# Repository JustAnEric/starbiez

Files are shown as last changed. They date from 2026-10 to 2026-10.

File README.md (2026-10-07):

# StarbieZ (star-beez)

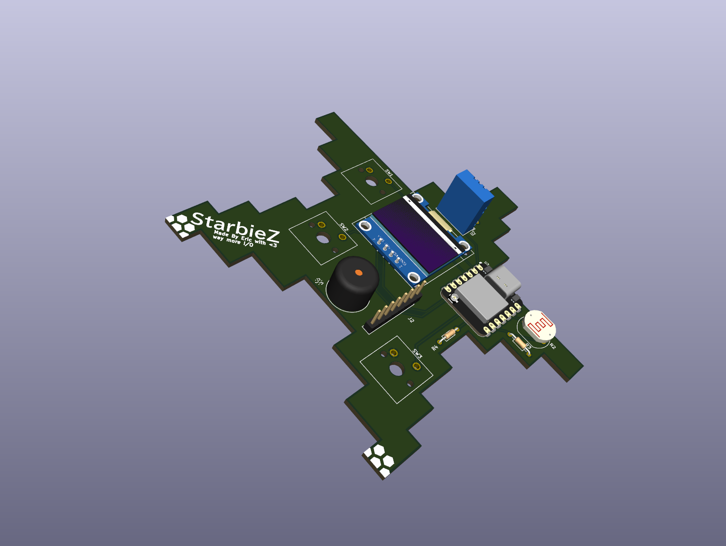
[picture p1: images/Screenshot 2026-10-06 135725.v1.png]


Starbiez is a redo of the [Starbie](https://github.com/SharKingStudios/Starbie), and boy it packs *serious* power!

You're now getting your own extendible Tamagotchi that can run MANY things, basically sort of like a *Flipper Zero Nano* but without the pentesting tools! (don't go hacking things around town with this... :C)

## What it does

the ESP32-S3 Plus is where I'd start the shift from MCU to CPU, and it's the main driver for this project. With 16 MB of flash and 8 MB of RAM, it's way more than all the classic Tamagotchis that had **1 KB of RAM and ROM**! this Starbie is equipped with greater environmental awareness, audio and just *one more* button that adds so many more possibilities for what can be done with this project.

the environment can be currently measured by these sensors:

* a light dependent resistor on the right front face of the board
* a DHT11 humidity sensor on the top front face of the board
* AND a 6 pin IMU called the MPU6050 at the bottom right of the board!

the outputs on this device are *pretty simple*:
* 128x64 SSD1306 OLED screen
* buzzer/piezo

you provide input to this project by literally just clicking the cherry MX keyboard switches... and the circuitpython software being packaged for this project is considerably extendable being based off of the C++/.INO software. (yes, I'm rewriting/have rewritten it to make it easier for extensions, welcome beginners!)

## The process of building
### Day 1!

I spent the whole day, and I quite probably went past 4 hours (the actual making time of my board) to include the things that would make it my own...

You can see the **timestamps in the screenshot names**, for journal purposes I didn't replace them with a generic name throughout my processes!

How to interpret them:

* Example: `Screenshot 2026-10-06 064450.png`
* `2026-`: The year
* `10-`: The month
* `06`: The day
* `064450`:
    * `06`: The hour of the day (in AEST/AEDT, since I'm working on it in Australia/Sydney!)
    * `44`: The minute of the hour `06`
    * `50`: The seconds the screenshot was taken at

Hope this helps!

1. I created the project and crafted the schematic from the [tutorial](https://github.com/SharKingStudios/Starbie)

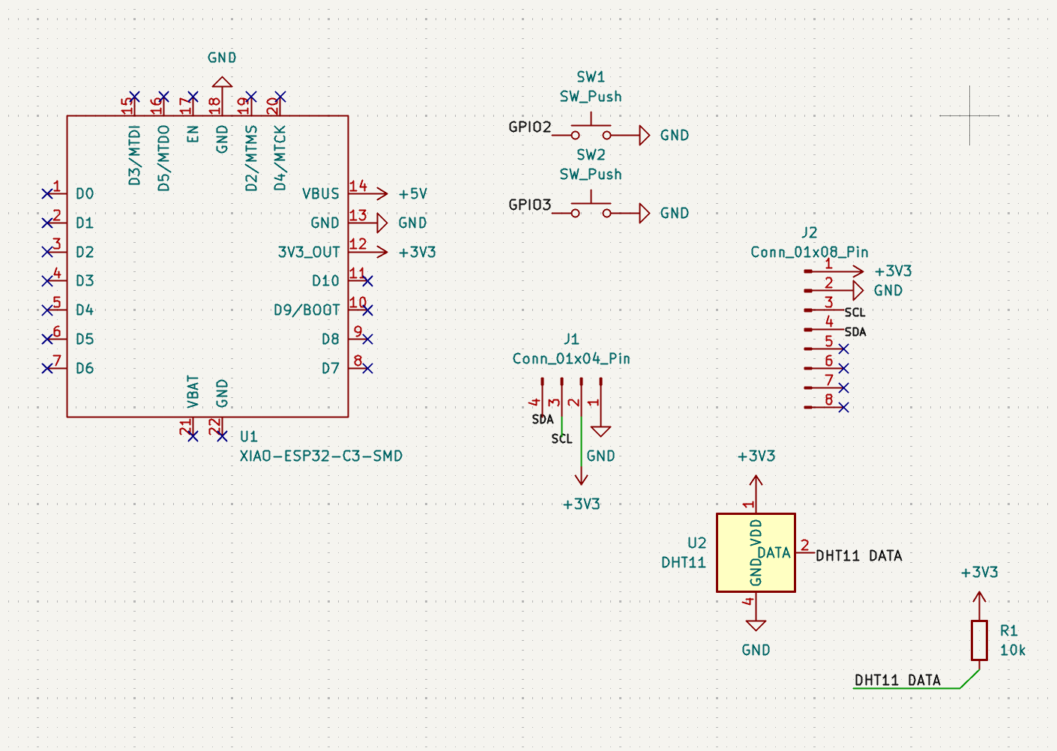
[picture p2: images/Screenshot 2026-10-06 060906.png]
    

2. I laid out my PCB, creating the star `Edge.Cuts` from a reference image I found on Google first

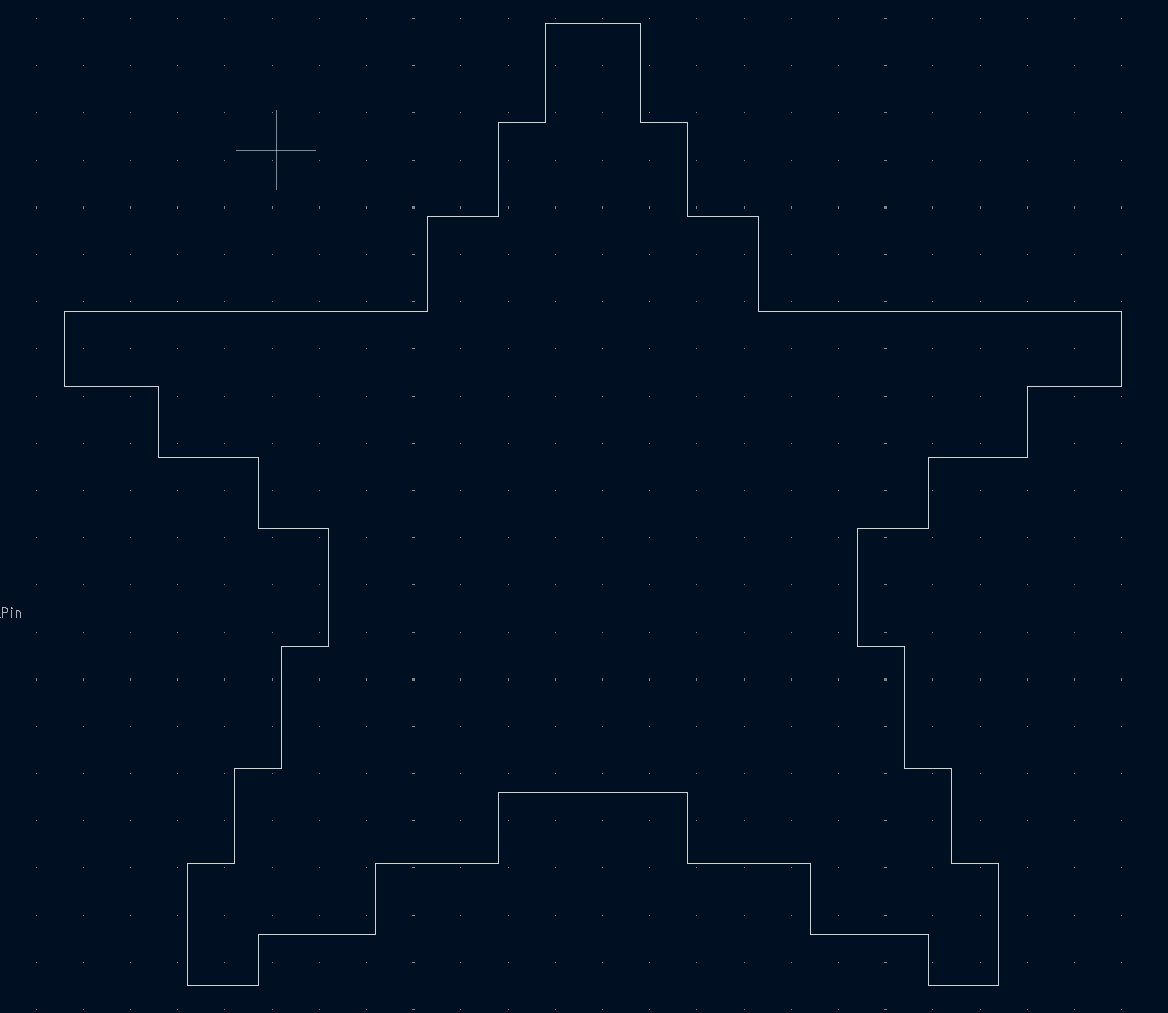
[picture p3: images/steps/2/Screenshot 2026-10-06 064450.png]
    
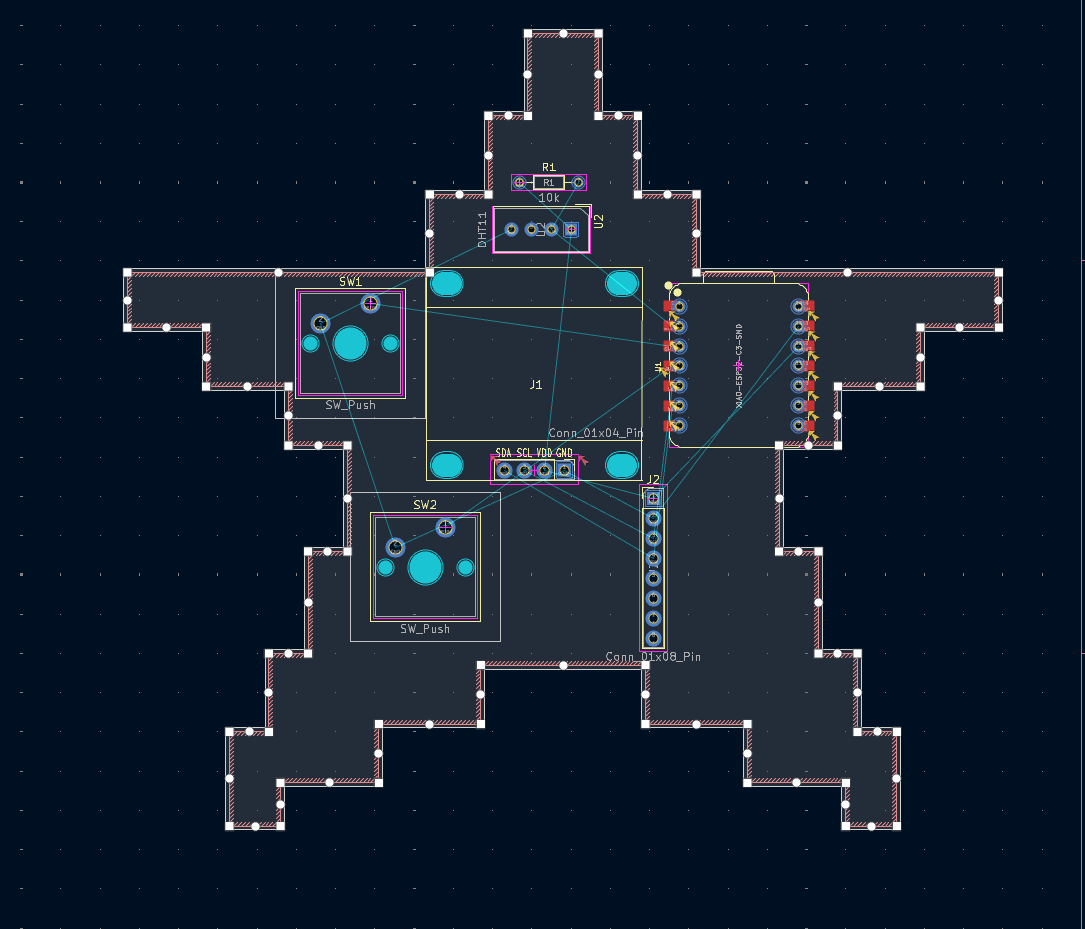
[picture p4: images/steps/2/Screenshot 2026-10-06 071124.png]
    

    and then the satisfying ground layer by the B button...
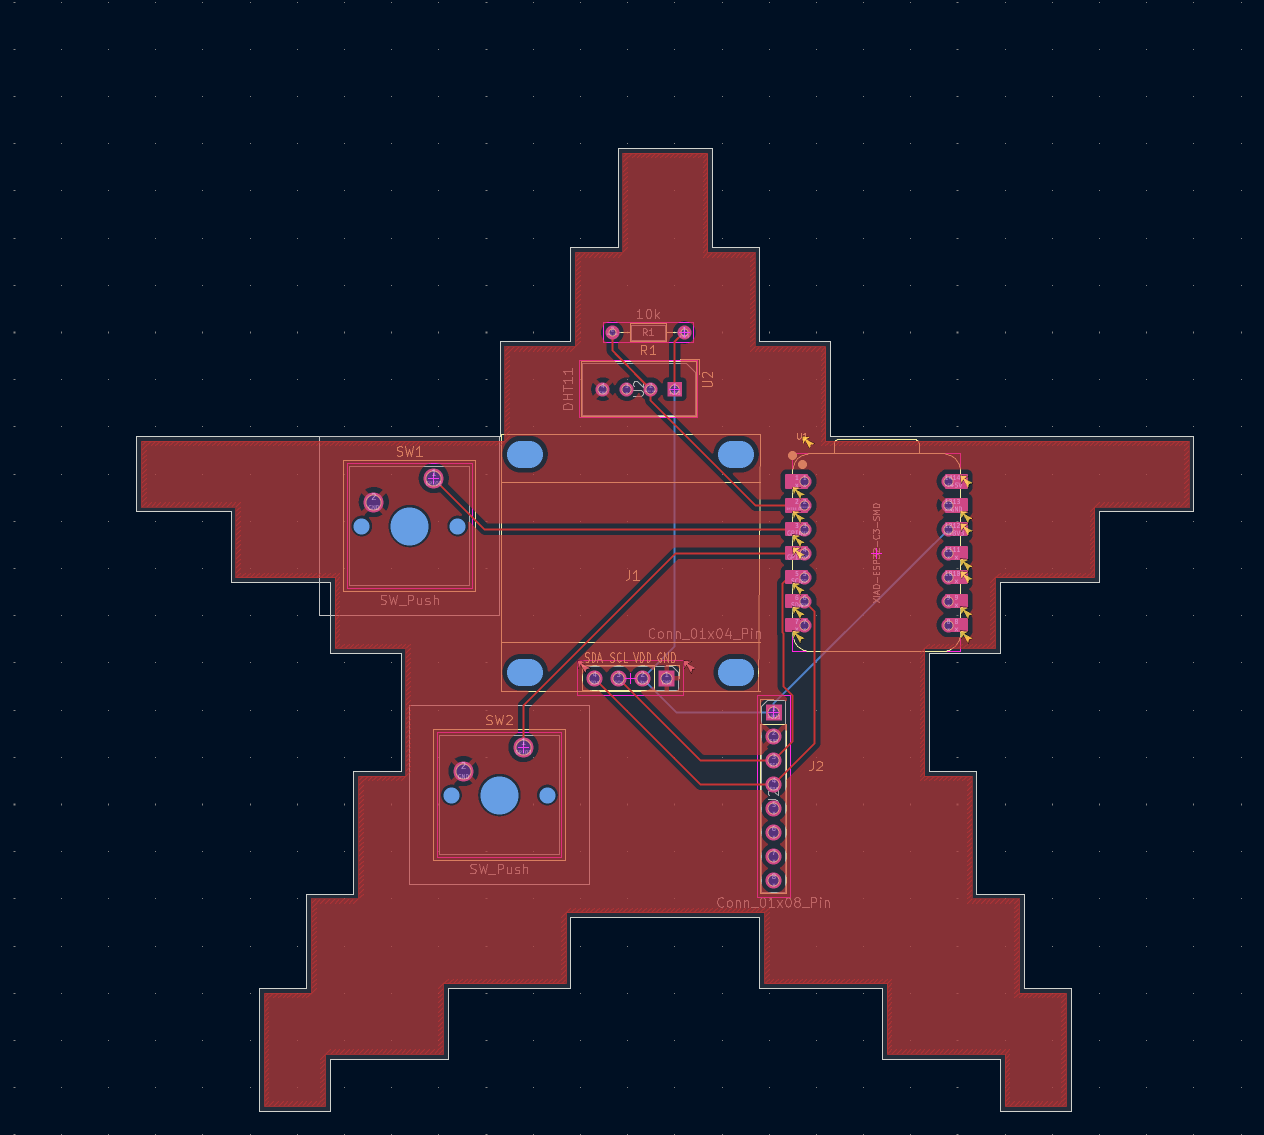
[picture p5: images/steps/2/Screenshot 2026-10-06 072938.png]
    

    Those steps took about 4 hours and 5 minutes, timed by Google stopwatch (thanks search engine monopoly... never mind)

3. One of my first modifications was with changing the MCU from an ESP32-C3 to an ESP32-S3. My first strongest candidate.

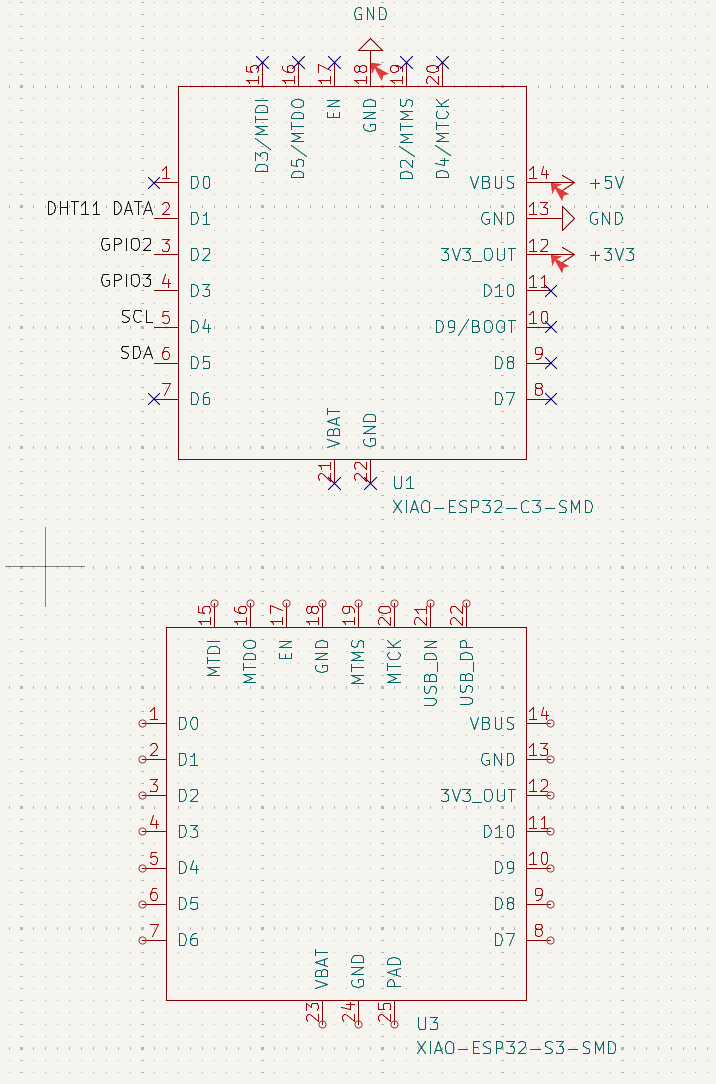
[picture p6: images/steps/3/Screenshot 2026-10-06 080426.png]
    

    This swap didn't take very long... They're very structurally similar. I made sure to check Seeed's official guides though, just in case I got the pinouts wrong.

4. I included a second sensor, the LDR03 (light-dependent resistor is what LDR stands for) and I made sure to include a fixed resistance of 10kΩ, though this would change later down the track in my realisation an LDR03 is VERY hard to source in the real world today...!

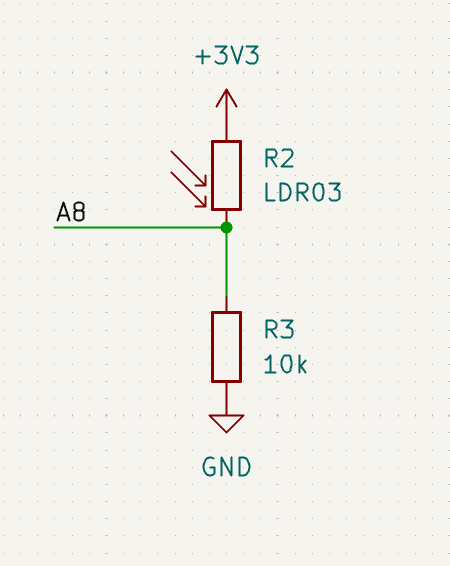
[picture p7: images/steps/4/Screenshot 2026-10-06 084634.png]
    

    Here's where I put it, on the right wing of the star :)

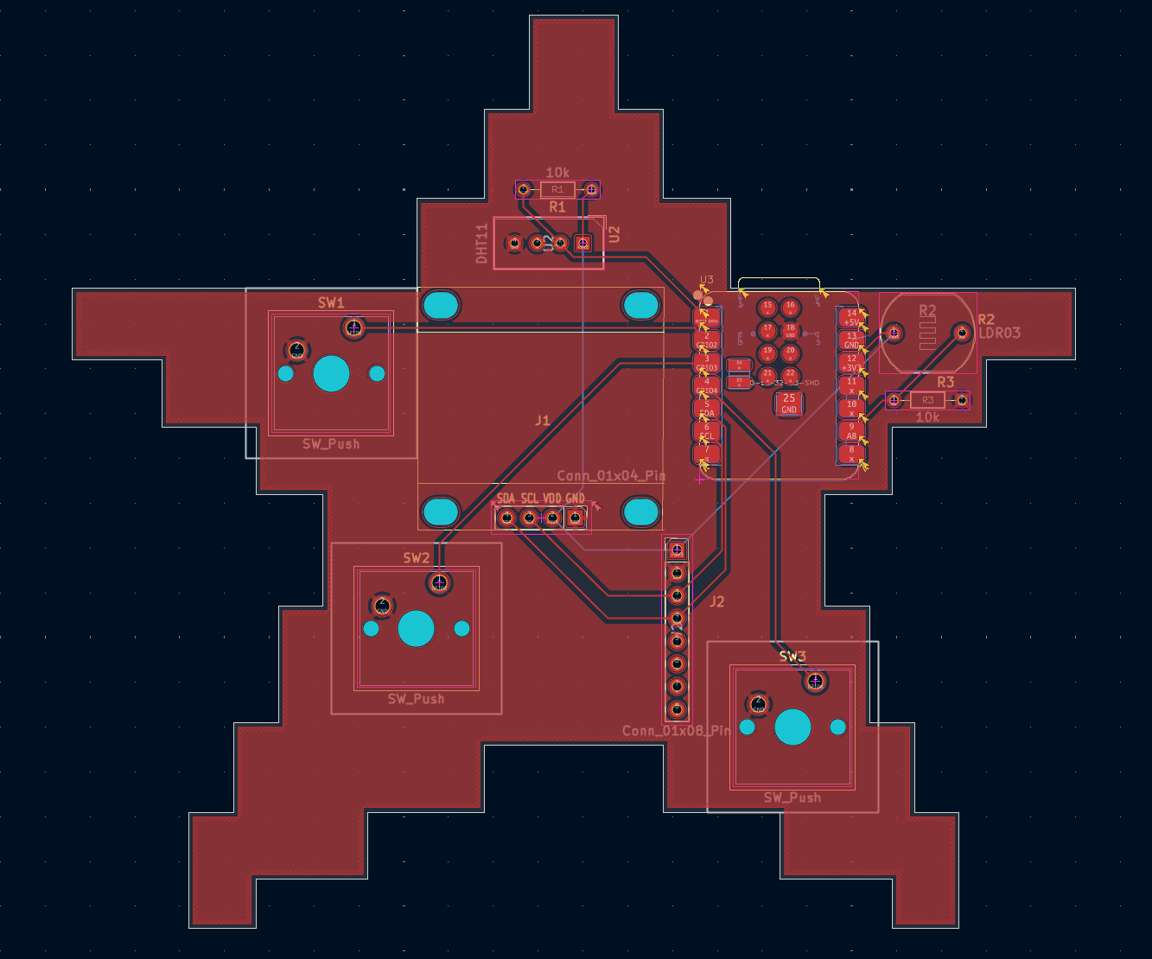
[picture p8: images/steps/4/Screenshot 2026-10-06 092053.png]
    

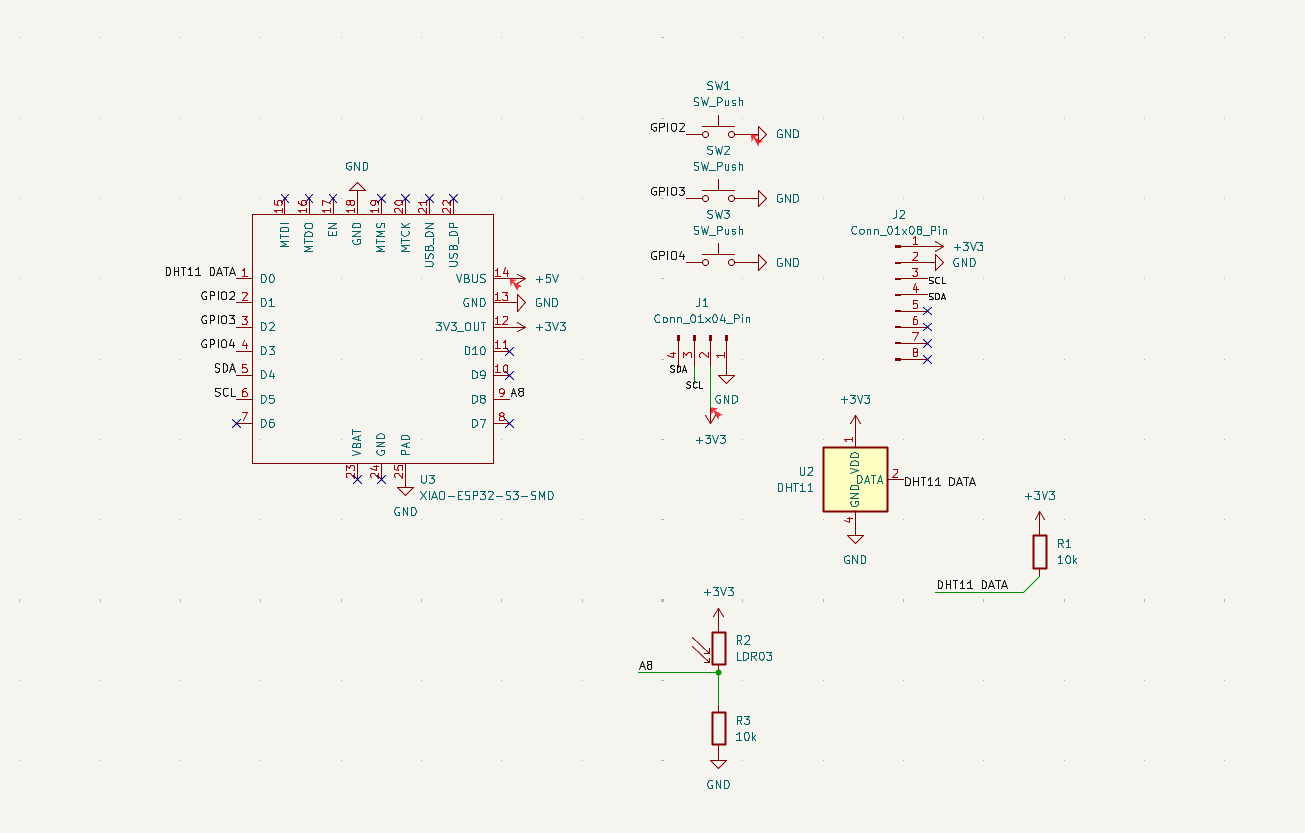
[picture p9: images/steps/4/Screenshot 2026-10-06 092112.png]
    

5. A lot of organisation, and another output was added! A buzzer or a piezo was inspired by the Sprig's design when I made my Columns game for them (still waiting for approval), and I feel this Tamagotchi would do *really* well with a bit of tunes.

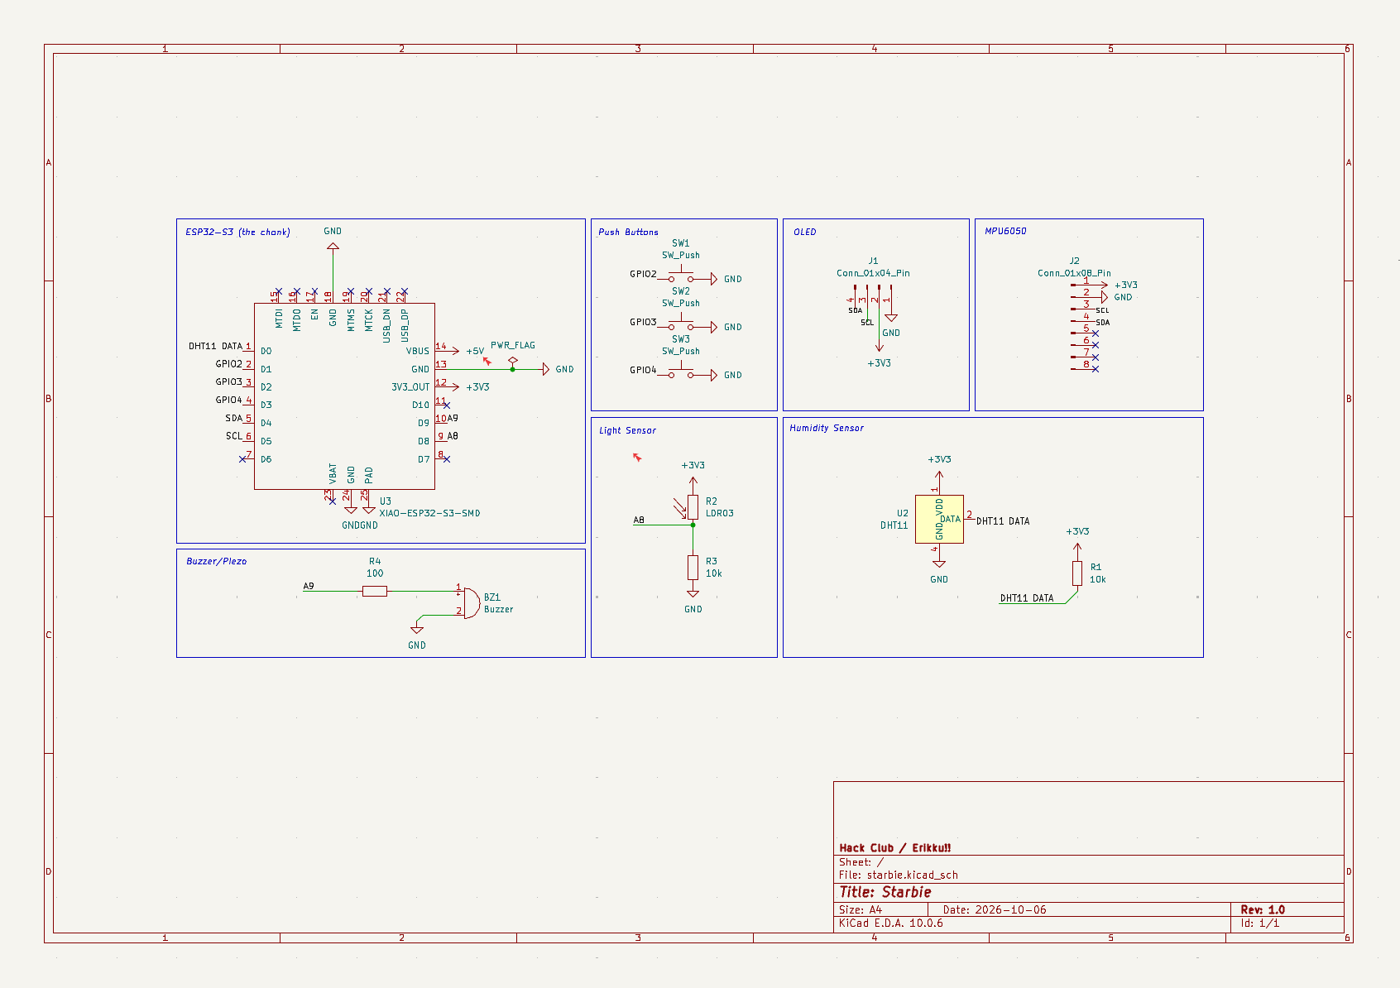
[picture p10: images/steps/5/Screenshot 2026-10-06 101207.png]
    
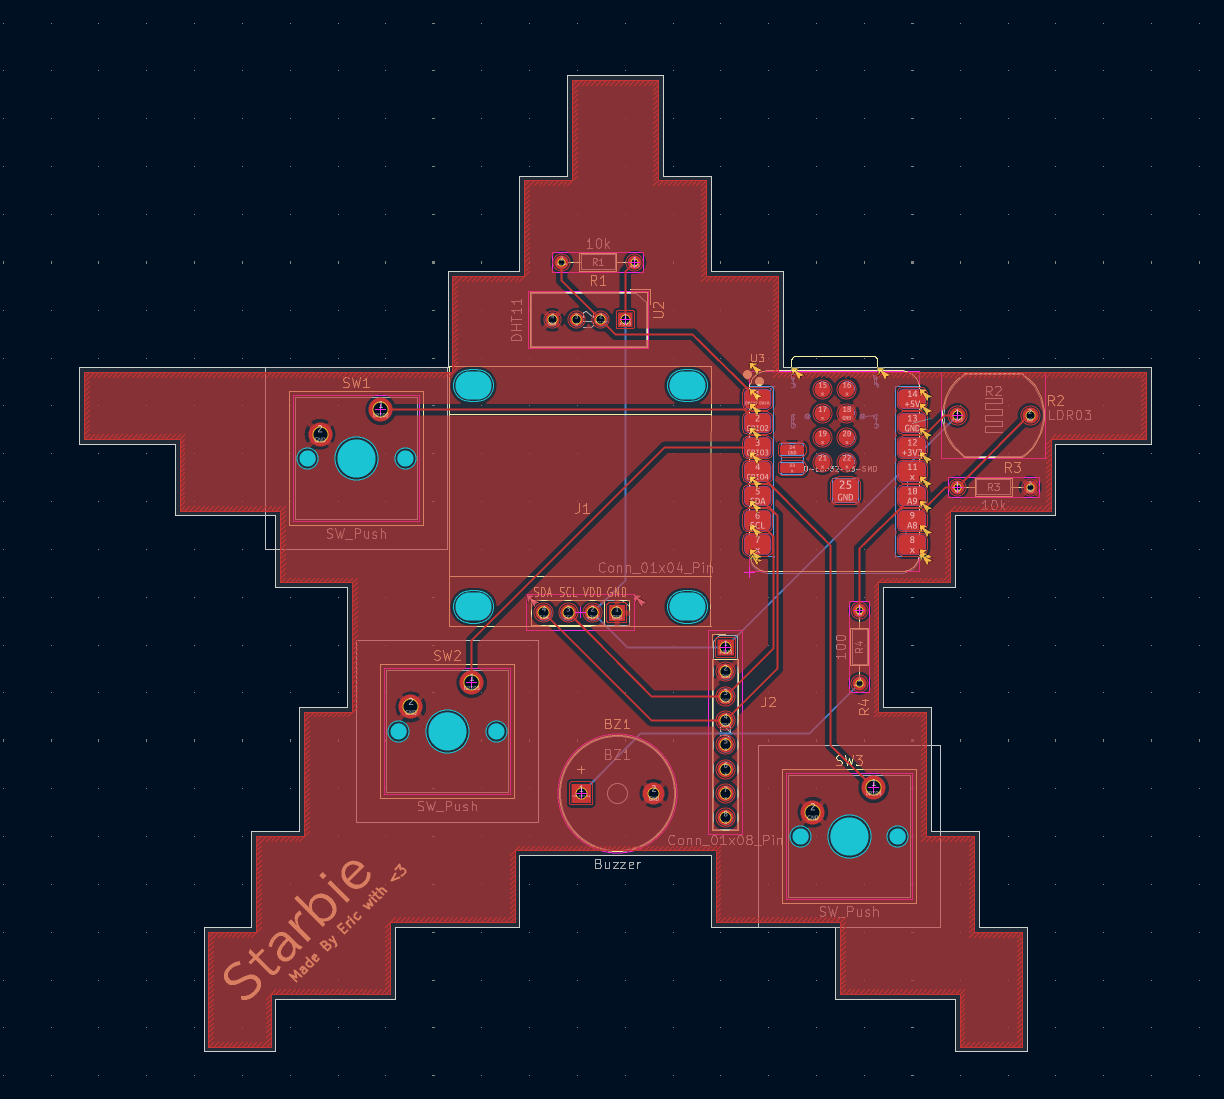
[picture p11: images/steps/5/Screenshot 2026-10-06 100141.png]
    

    I put in a little resistor to prevent any surge back to the tiny ESP... yeah it's pretty small.

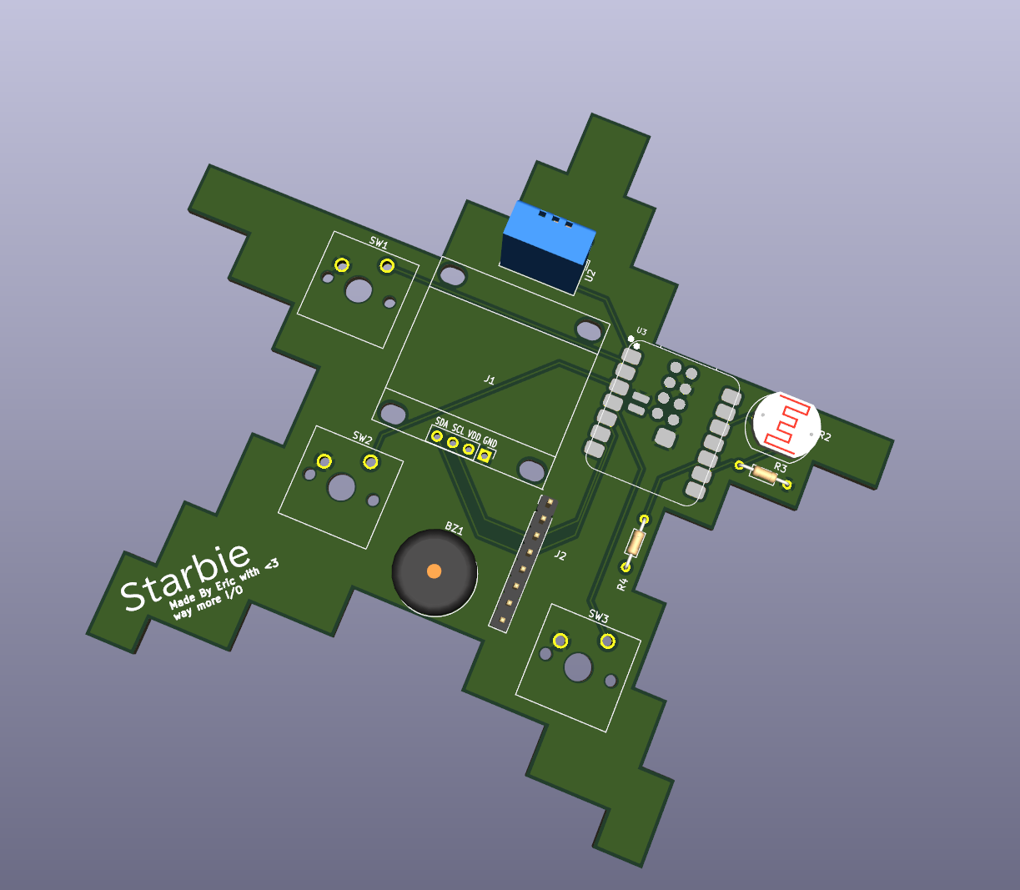
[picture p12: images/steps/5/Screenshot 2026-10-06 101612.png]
    

6. I found a honeycomb SVG on Flaticon and I decided to use it for the two bottom corners of the board to add some more decoration!

    

    This was also the time I figured out how to get the 3D models into the footprints, I spent a long time trying to figure out how to get into the footprint editor...

7. Realizing there was not enough clearance for poor Switch 3 around J2, I had to make a few changes. And these changes would be for the better, it's now a dev board... :P It's when I made the switch to the ESP32-S3 Plus to get more GPIO. This is when my board started to look a lot more like trace spaghetti, but it's okay... (I am guessing)

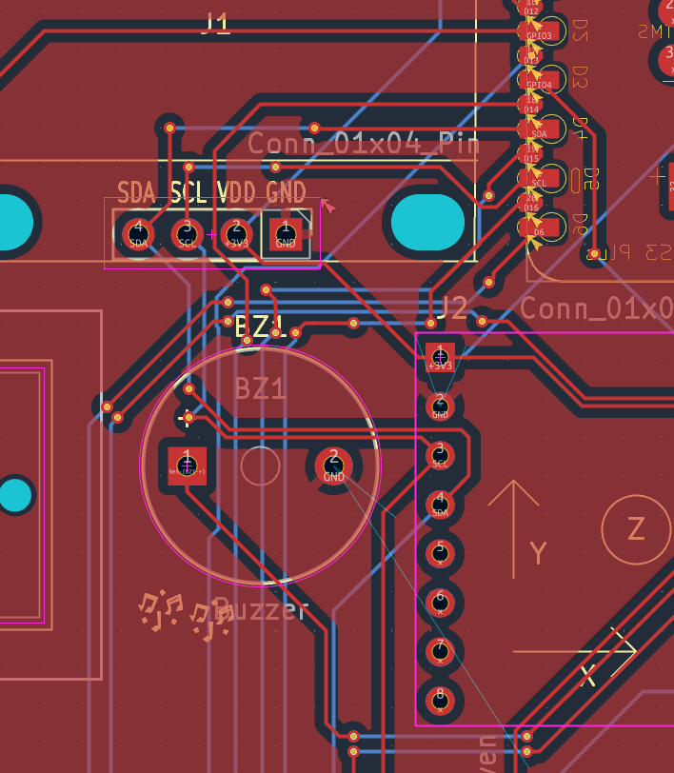
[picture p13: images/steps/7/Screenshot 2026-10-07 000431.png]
    

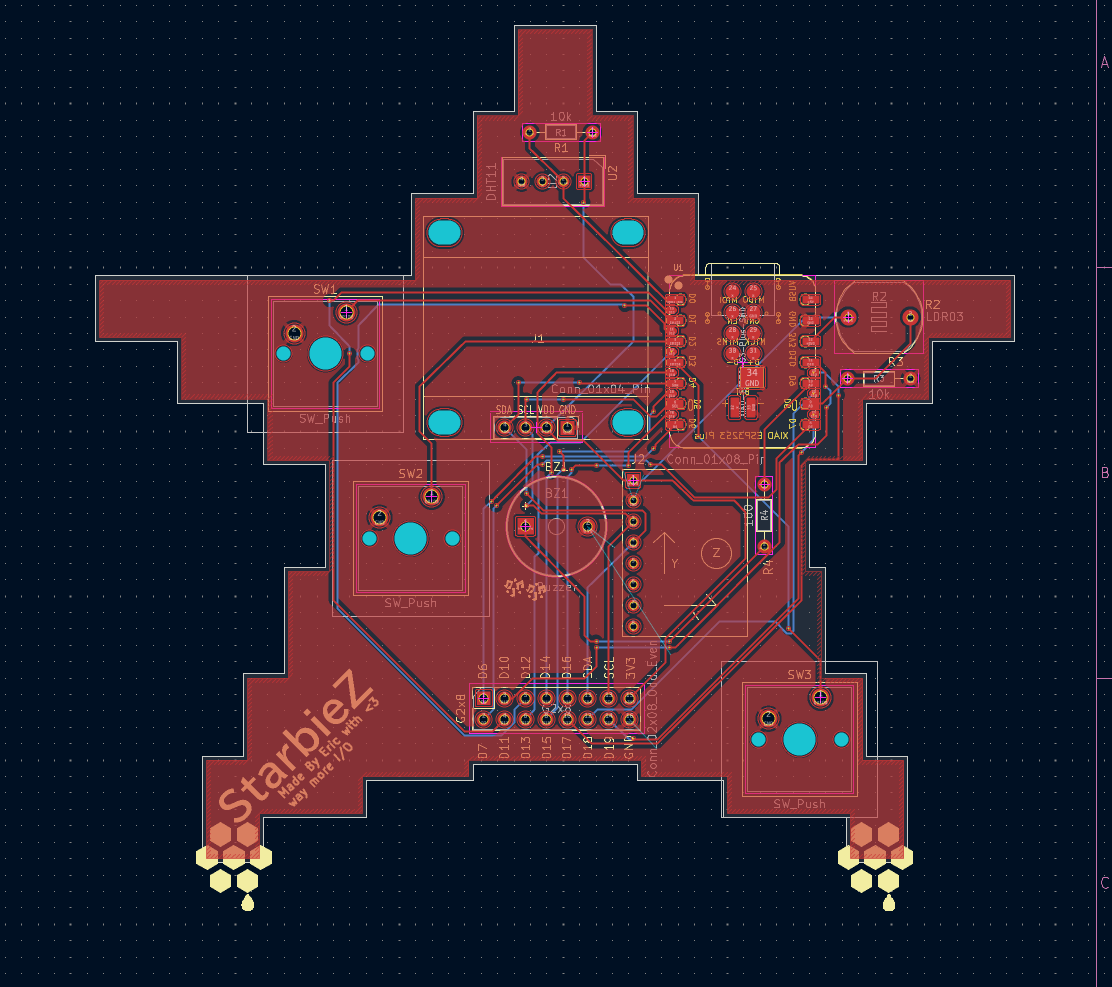
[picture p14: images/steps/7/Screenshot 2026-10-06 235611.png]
    

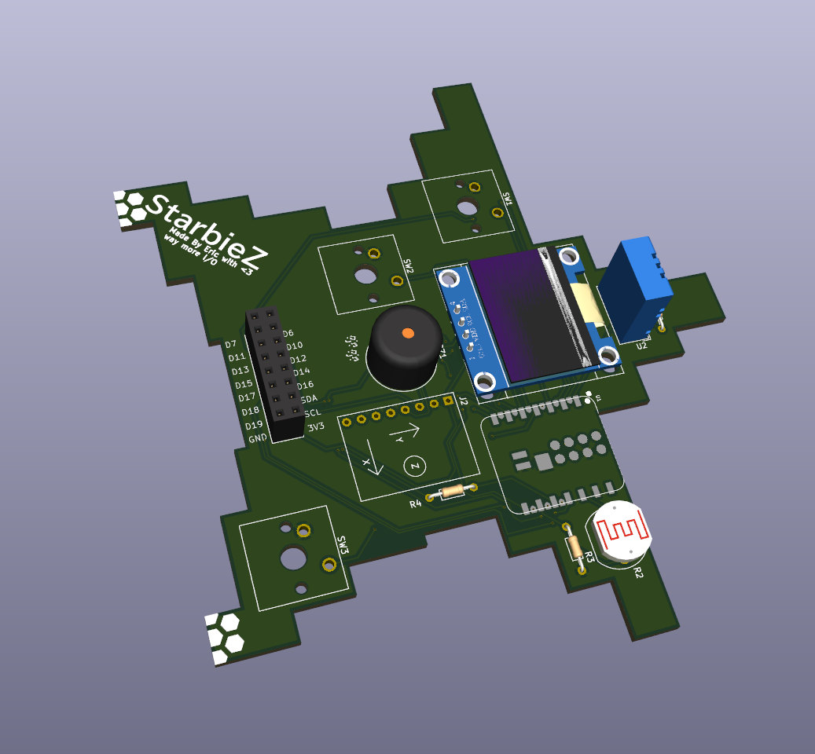
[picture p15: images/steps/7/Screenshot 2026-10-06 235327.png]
    

    Now there's odd-even 2x8 GPIO female pins on the board, featuring these that go to the ESP32-S3 Plus! Go from right to left if you flip the Starbiez on it's right side:

    | Pin | GPIO |
    |-----|------|
    | 1 (right) | D6 |
    | 2 (left) | D7 |
    | 3 (right) | D10 |
    | 4 (left) | D11 |
    | 5 (right) | D12 |
    | 6 (left) | D13 |
    | 7 (right) | D14 |
    | 8 (left) | D15 |
    | 9 (right) | D16 |
    | 10 (left) | D17 |
    | 11 (right) | SDA (for I2C!) |
    | 12 (left) | D18 |
    | 13 (right) | SCL (for I2C!) |
    | 14 (left) | D19 |
    | 15 (right) | 3V3 output, make sure not to draw too much! |
    | 16 (left) | board GND |

    <details>
    <summary>Pin reference image for you nerds...</summary>

    > ## Front
    >
    > (https://files.seeedstudio.com/wiki/SeeedStudio-XIAO-ESP32S3/img/XIAO_ESP32-S3_Plus_front_pinout.png)
    >
    > ## Back
    > (https://files.seeedstudio.com/wiki/SeeedStudio-XIAO-ESP32S3/img/XIAO_ESP32-S3_Plus_back_pinout.png)

    </details>

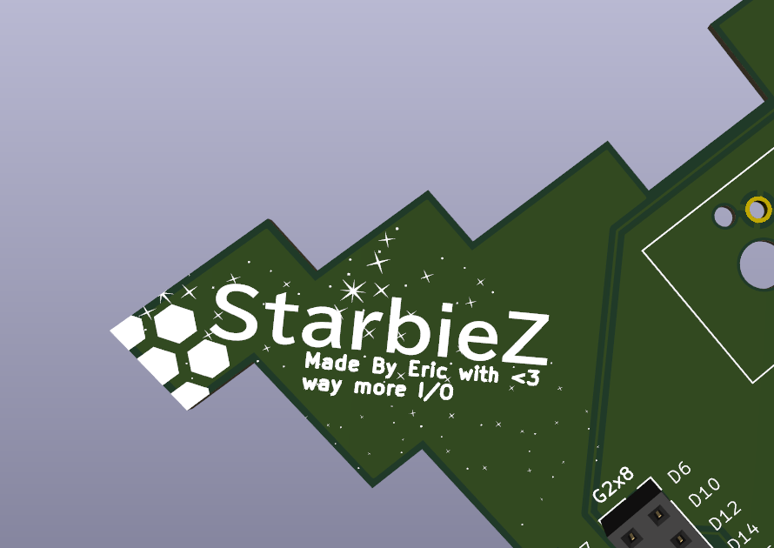
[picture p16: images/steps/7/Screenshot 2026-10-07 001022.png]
    

    (*sparkles*!!) The sparkles I got from Claude, I asked it to make a flat monochrome white sparkle SVG graphic I could use... I plastered it onto the board on all the corners.

8. Around this time, I was searching for good parts to use on AliExpress, but I found that shipping from China is a *little* bit too expensive for the grant I'm receiving. I then got a little distracted, still worrying myself about whether the light-dependent resistor I've wired up would be correct. More research got me to change it to a generic one, so here's the LDR part I recommend if anyone tries to build this project:

    | Specification | Value |
    |---------------|-------|
    | dark resistance (pitch black, 0 lux) | ~10MΩ |
    | light resistance (10 lux) | 8kΩ to 20kΩ |
    | max dissipation | 100mW
    | form factor | THT ~5mm |
    | ideally... | the GL5528 |

    I also switched the fixed resistance to 100kΩ so the ESP32-S3 Plus receives a more controlled value than in **0.03 V** or completely uncharted territory...

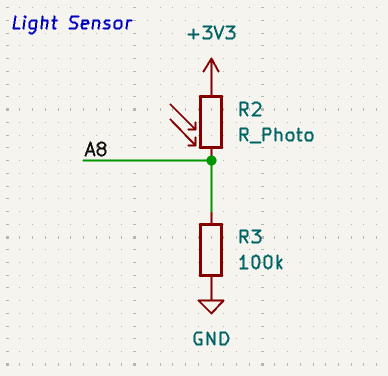
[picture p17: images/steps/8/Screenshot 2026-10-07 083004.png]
    

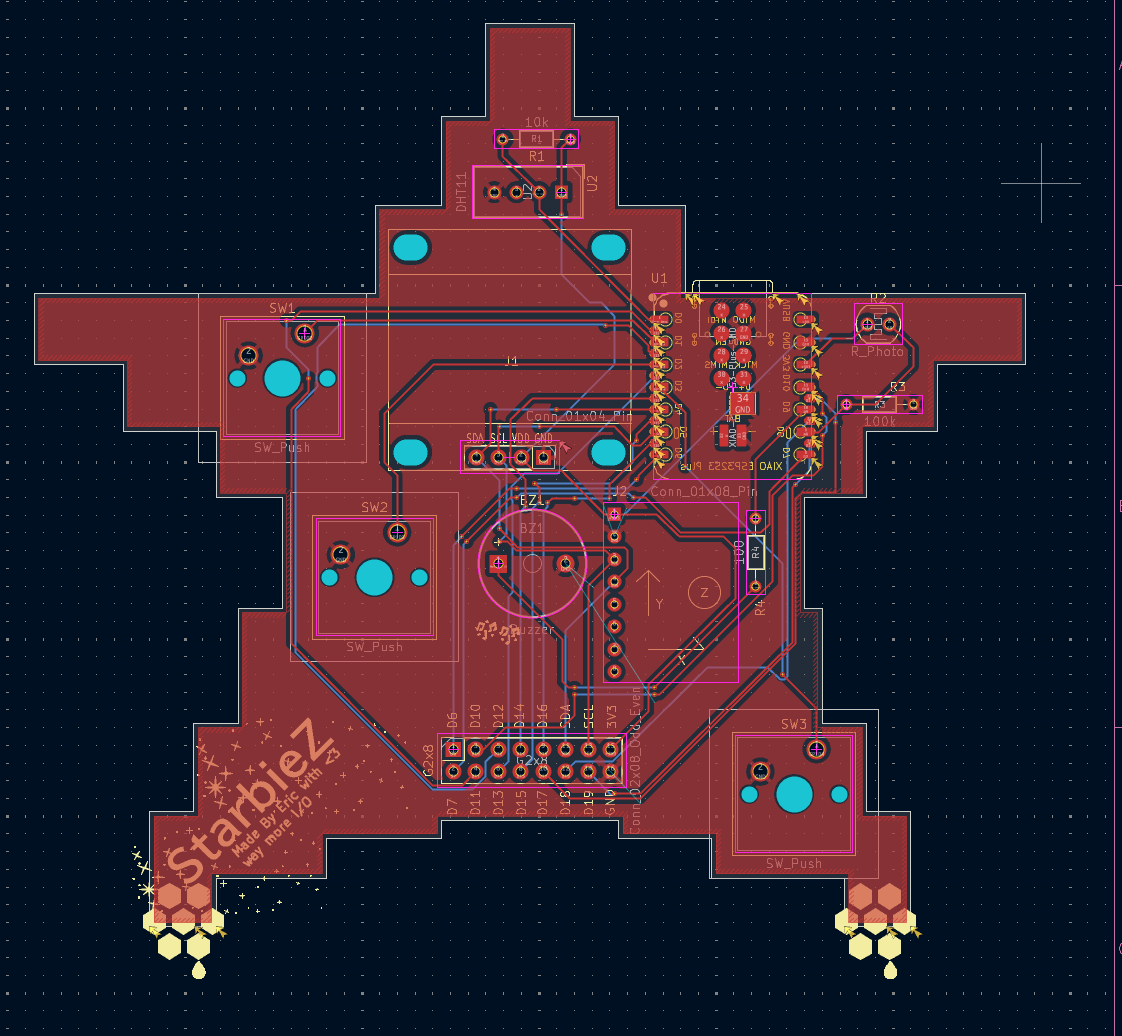
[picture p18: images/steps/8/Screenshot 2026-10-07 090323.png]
    

this took me the ENTIRETY of yesterday to build it and some of today to refine it, in retrospect I got up really early some days :| it took me about 1 hour and 22 minutes to write this writeup, according to Hackatime. I hope every viewer likes this project of mine!

## Software

I extended/am extending CircuitPython for this project for providing user access to an API, you can view my extensions to CircuitPython [here](https://github.com/JustAnEric/starbiez-circuitpython)! It's recommended to use this instead of normal CircuitPython on your ESP32-S3, as you probably won't have access to much easy modifications.

## Ending README

hopefully Hack Club likes this little project of mine, so I can keep developing it more and more... I'm definitely pushing boundaries here with what can be done, but...

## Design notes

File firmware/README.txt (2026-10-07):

Do NOT flash this firmware to your StarbieZ without seeing https://github.com/JustAnEric/starbiez-circuitpython first!

If you do, your project will error in terms of modularity, and **not** start or do anything!

Modularity allows you to edit your StarbieZ device without editing code.py in the form of JerryScript files.

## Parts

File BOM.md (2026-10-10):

# StarbieZ – bill of materials

<!-- Generated by Half Life from project cmuv2wpkk0cyp01sm96t8f5om. Edits here are overwritten on the next sync. -->
<!-- Generated: 2026-10-10T14:39:48.990Z -->

> [!NOTE]
> This parts list is mirrored from [Half Life](https://halflife.hackclub.com). Editing it here will not change the platform's copy, and the next sync overwrites this file.

| Week | Tier | Parts funding |
| --- | --- | --- |
| Week 1 | Tier 2 | $65.00 |

| Part | What it's for | Qty | Unit | Total | Vendor |
| --- | --- | --- | --- | --- | --- |
| [ESP32-S3 Plus](https://www.pakronics.com.au/products/seeed-studio-xiao-esp32s3-plus-20-gpios-2-4ghz-wifi-ble-5-0-8mb-psram-16mb-flash-esp32-s3-dual-core-battery-charge-supported-ss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) | Main loop, more GPIO | 1 | $11.50 | $11.50 | [Pakronics](https://www.pakronics.com.au/products/seeed-studio-xiao-esp32s3-plus-20-gpios-2-4ghz-wifi-ble-5-0-8mb-psram-16mb-flash-esp32-s3-dual-core-battery-charge-supported-ss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) |
| [Gateron Milky Pro Switches (10pcs)](https://www.aliexpress.com/item/1005006425450443.html) | Switches and satisfying clicks | 1 | $3.85 | $3.85 | [AliExpress](https://www.aliexpress.com/item/1005006425450443.html) |
| [White 128x64 OLED display](https://www.aliexpress.com/item/1005004355547926.html) | The face of Starbiez | 1 | $3.09 | $3.09 | [AliExpress](https://www.aliexpress.com/item/1005004355547926.html) |
| [DHT22 Chip](https://core-electronics.com.au/dht22-temperature-and-relative-humidity-sensor-module.html) | For improved humidity sensing | 1 | $2.38 | $2.38 | [Core Electronics](https://core-electronics.com.au/dht22-temperature-and-relative-humidity-sensor-module.html) |
| [MPU6050 3-axis IMU](https://www.aliexpress.com/item/1005007989748804.html) | For shaking Starbiez | 1 | $2.92 | $2.92 | [Core Electronics](https://www.aliexpress.com/item/1005007989748804.html) |
| [600 Pack of 1/4 Watt 1% Resistors (30 values, 20 of each)](https://core-electronics.com.au/600-pack-of-1-4-watt-1-resistors-30-values-20-of-each.html) | For resistance in the circuit | 1 | $1.87 | $1.87 | [Core Electronics](https://core-electronics.com.au/600-pack-of-1-4-watt-1-resistors-30-values-20-of-each.html) |
| [Light dependent resistor](https://core-electronics.com.au/light-dependent-resistor-ldr.html) | For helping Starbiez sleep | 1 | $0.22 | $0.22 | [Core Electronics](https://core-electronics.com.au/light-dependent-resistor-ldr.html) |
| [Generic buzzer (⌀11 x 9)](https://core-electronics.com.au/piezo-buzzer.html) | For buzzing through menus (sound interactivity and accessibility) | 1 | $0.22 | $0.22 | [Core Electronics](https://core-electronics.com.au/piezo-buzzer.html) |
| [0.100" (2.54 mm) Female Header: 2x8-Pin, Straight](https://core-electronics.com.au/0-100-2-54-mm-female-header-2x8-pin-straight.html) | For GPIO connectivity (if anyone wanted to use this as a devboard) | 1 | $2.16 | $2.16 | [Core Electronics](https://core-electronics.com.au/0-100-2-54-mm-female-header-2x8-pin-straight.html) |
| [Mint Green MA Keycaps for MX Compatible Switches (5pcs)](https://core-electronics.com.au/mint-green-ma-keycaps-for-mx-compatible-switches-5-pack.html) | For topping off the Gateron Milky Pro Switches | 1 | $6.00 | $6.00 | [Core Electronics](https://core-electronics.com.au/mint-green-ma-keycaps-for-mx-compatible-switches-5-pack.html) |
| **Parts subtotal** | — | — | — | **$34.21** | — |
| **Tax & shipping** | — | — | — | **$15.63** | — |
| **Total** | — | — | — | **$49.84** | — |

$15.16 left of the tier's funding.

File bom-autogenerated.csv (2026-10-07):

Reference | Qty | Value | DNP | Exclude from BOM | Exclude from Board | Exclude from Simulation | Exclude from Position Files | Footprint | Datasheet
BZ1 | 1 | Buzzer |  |  |  |  | ${EXCLUDE_FROM_POS_FILES} | Buzzer_Beeper:Buzzer_12x9.5RM7.6
G2x8 | 1 | Conn_02x08_Odd_Even |  |  |  |  | ${EXCLUDE_FROM_POS_FILES} | Connector_PinSocket_2.54mm:PinSocket_2x08_P2.54mm_Vertical
J1 | 1 | Conn_01x04_Pin |  |  |  |  | ${EXCLUDE_FROM_POS_FILES} | Project:Display_128x64_096_I2C
J2 | 1 | Conn_01x08_Pin |  |  |  |  | ${EXCLUDE_FROM_POS_FILES} | Project:MPU6050_Module
R1 | 1 | 10k |  |  |  |  | ${EXCLUDE_FROM_POS_FILES} | Resistor_THT:R_Axial_DIN0204_L3.6mm_D1.6mm_P7.62mm_Horizontal
R2 | 1 | R_Photo |  |  |  |  | ${EXCLUDE_FROM_POS_FILES} | OptoDevice:R_LDR_4.9x4.2mm_P2.54mm_Vertical
R3 | 1 | 100k |  |  |  |  | ${EXCLUDE_FROM_POS_FILES} | Resistor_THT:R_Axial_DIN0204_L3.6mm_D1.6mm_P7.62mm_Horizontal
R4 | 1 | 100 |  |  |  |  | ${EXCLUDE_FROM_POS_FILES} | Resistor_THT:R_Axial_DIN0204_L3.6mm_D1.6mm_P7.62mm_Horizontal
SW1,SW2,SW3 | 3 | SW_Push |  |  |  |  | ${EXCLUDE_FROM_POS_FILES} | Button_Switch_Keyboard:SW_Cherry_MX_1.00u_PCB
U1 | 1 | XIAO-ESP32-S3-Plus-SMD |  |  |  |  | ${EXCLUDE_FROM_POS_FILES} | Project:XIAO-ESP32-S3-Plus-SMD
U2 | 1 | DHT11 |  |  |  |  | ${EXCLUDE_FROM_POS_FILES} | Sensor:Aosong_DHT11_5.5x12.0_P2.54mm | http://akizukidenshi.com/download/ds/aosong/DHT11.pdf

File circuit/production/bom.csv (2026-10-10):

Designator | Footprint | Quantity | Value | LCSC Part #
BZ1 | Buzzer_12x9.5RM7.6 | 1 | Buzzer
DHT1 | PinSocket_1x04_P2.54mm_Vertical | 1 | DHT
G2X8 | PinSocket_2x08_P2.54mm_Vertical | 1 | Conn_02x08_Odd_Even
J1 | Display_128x64_096_I2C | 1 | Conn_01x04_Pin
J2 | MPU6050_Module | 1 | Conn_01x08_Pin
R1, R3 | R_Axial_DIN0204_L3.6mm_D1.6mm_P7.62mm_Horizontal | 2 | 10k
R2 | R_LDR_4.9x4.2mm_P2.54mm_Vertical | 1 | R_Photo
R4 | R_Axial_DIN0204_L3.6mm_D1.6mm_P7.62mm_Horizontal | 1 | 100
SW1, SW2, SW3 | SW_Cherry_MX_1.00u_PCB | 3 | SW_Push
U1 | XIAO-ESP32-S3-Plus-SMD | 1 | XIAO-ESP32-S3-Plus-SMD

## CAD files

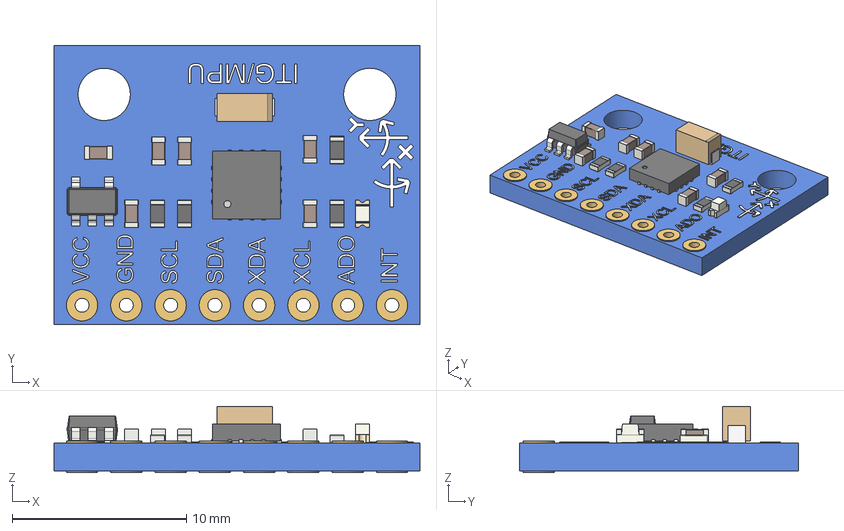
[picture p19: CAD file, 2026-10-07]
circuit/3D Models/GY-521_MPU6050 Accelerometer.step
21.0 x 16.0 x 3.80 mm
PCB
trou1
trou002
trou003
trou004
trou005
trou006
trou007
trou008
Text_X
Symb_Y
Symb_X
Text_Y
Text_VCC
Text_GND
Text_SCL
Text_SDA
Text_XDA
Text_XCL
Text_ADO
Text_INT
R_0603_1608Metric
R_0603_1608Metric001
R_0603_1608Metric002
R_0603_1608Metric003
C_0603_1608Metric
C_0603_1608Metric001
C_0603_1608Metric002
C_0603_1608Metric003
Corps002
Corps001 (Mirror #1)
C_0603_1608Metric004
C_0603_1608Metric005
LED_0603_1608Metric_Castellated
QFN_16_1EP_4x4mm_P065mm_EP21x21mm
Text_ITGMPU
SOT_23_5
Corps001

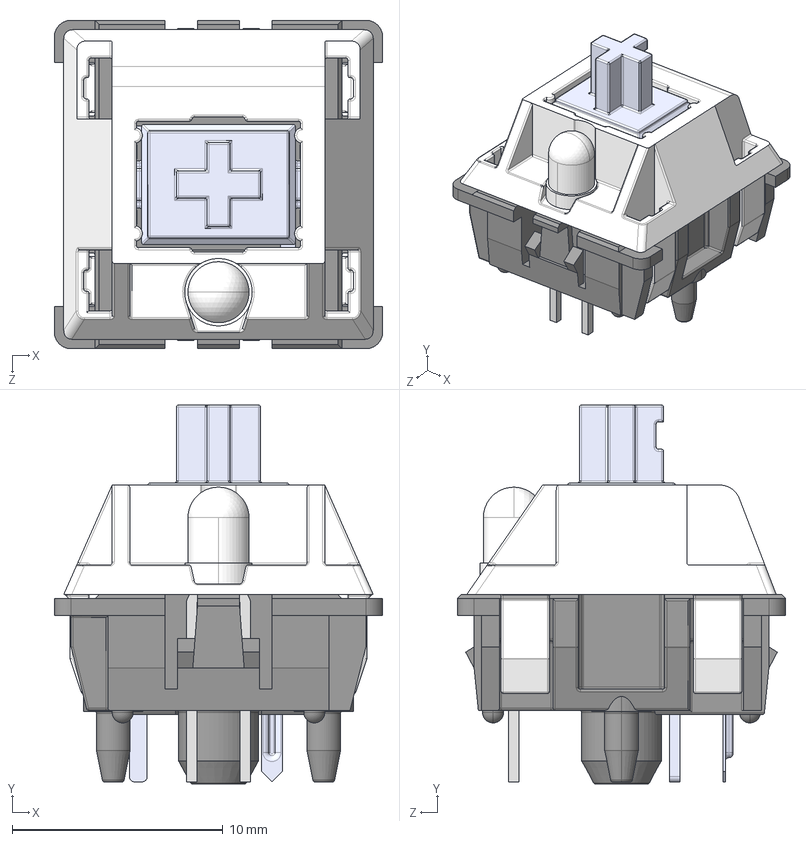
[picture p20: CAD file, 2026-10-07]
circuit/3D Models/Cherry MX.STEP
15.6 x 18.0 x 15.6 mm
Bottom
Pulsador
Top
Pieza5^Cherry MX
Pin1
Pin2
Led 3mm_trans

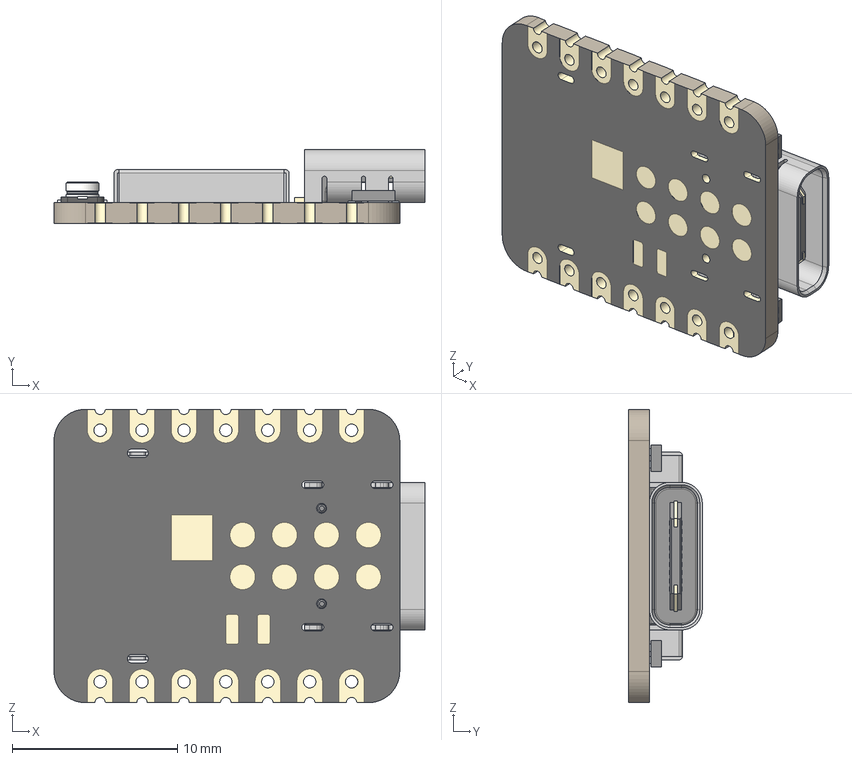
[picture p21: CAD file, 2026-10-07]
circuit/3D Models/XIAO-ESP32S3 v2.step
22.5 x 4.46 x 17.8 mm
BOSS-EXTRUDE14_8_
BOSS-EXTRUDE7_4_
BOSS-EXTRUDE7_3_
BOSS-EXTRUDE14_4_
BOSS-EXTRUDE14_2_
BOSS-EXTRUDE14_11_
BOSS-EXTRUDE7_7_
BOSS-EXTRUDE14_9_
BOSS-EXTRUDE14_3_
BOSS-EXTRUDE14_7_
MIRROR2
BOSS-EXTRUDE14_5_
BOSS-EXTRUDE14_12_
BOSS-EXTRUDE7_8_
BOSS-EXTRUDE7_1_
BOSS-EXTRUDE14_10_
BOSS-EXTRUDE7_9_
BOSS-EXTRUDE14_6_
BOSS-EXTRUDE14_1_
BOSS-EXTRUDE7_6_
BOSS-EXTRUDE7_2_
CUT-EXTRUDE5
BOSS-EXTRUDE7_5_
Shield
Pins x 2
U.FL-R-SMT-1_10_ v1

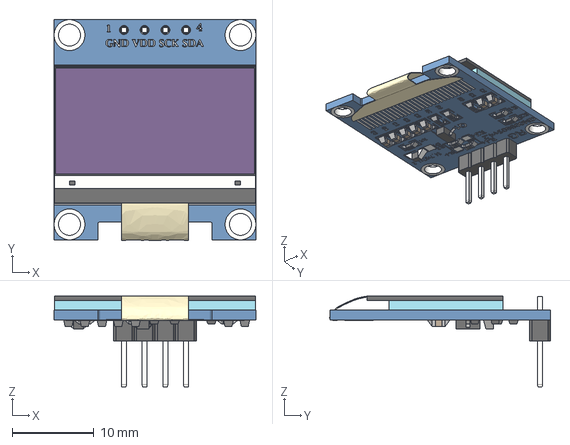
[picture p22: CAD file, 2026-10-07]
circuit/3D Models/0.96'' OLED Display.step
24.8 x 27.1 x 11.1 mm

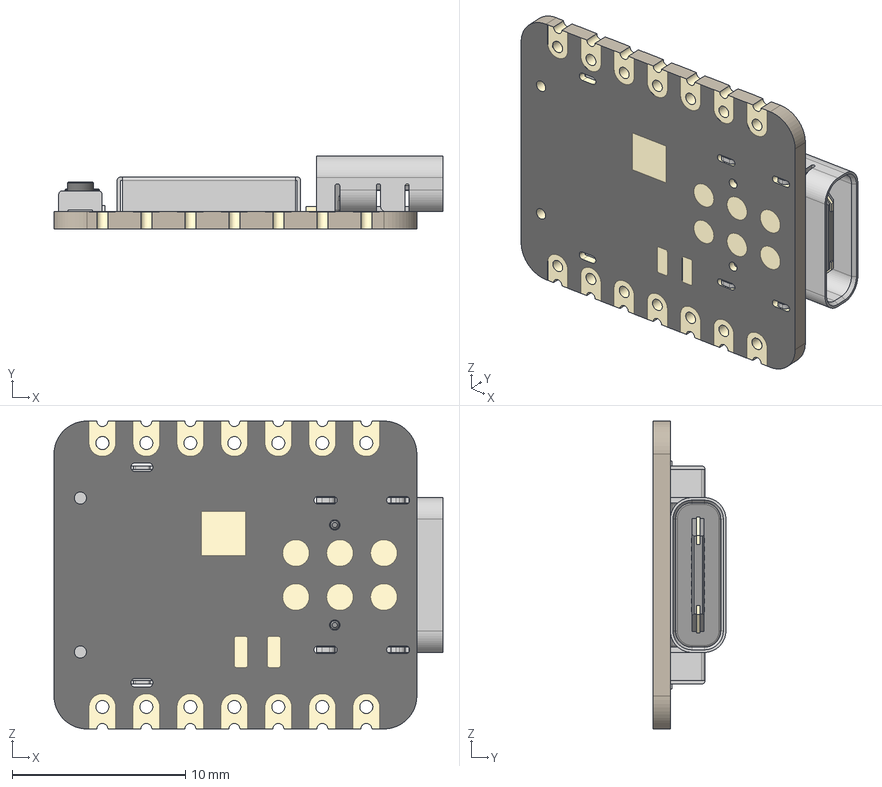
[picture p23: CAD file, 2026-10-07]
circuit/3D Models/Seeed Studio XIAO-ESP32-C3.step
22.5 x 4.21 x 17.8 mm
BOSS-EXTRUDE14_8_
BOSS-EXTRUDE7_4_
BOSS-EXTRUDE7_3_
BOSS-EXTRUDE14_4_
BOSS-EXTRUDE14_2_
BOSS-EXTRUDE14_11_
BOSS-EXTRUDE7_7_
BOSS-EXTRUDE14_9_
BOSS-EXTRUDE14_3_
BOSS-EXTRUDE14_7_
MIRROR2
BOSS-EXTRUDE14_5_
BOSS-EXTRUDE14_12_
BOSS-EXTRUDE7_8_
BOSS-EXTRUDE7_1_
BOSS-EXTRUDE14_10_
BOSS-EXTRUDE7_9_
BOSS-EXTRUDE14_6_
BOSS-EXTRUDE14_1_
BOSS-EXTRUDE7_6_
BOSS-EXTRUDE7_2_
CUT-EXTRUDE5
BOSS-EXTRUDE7_5_
U.FL Connector v1
Button (1) x 2
Shield

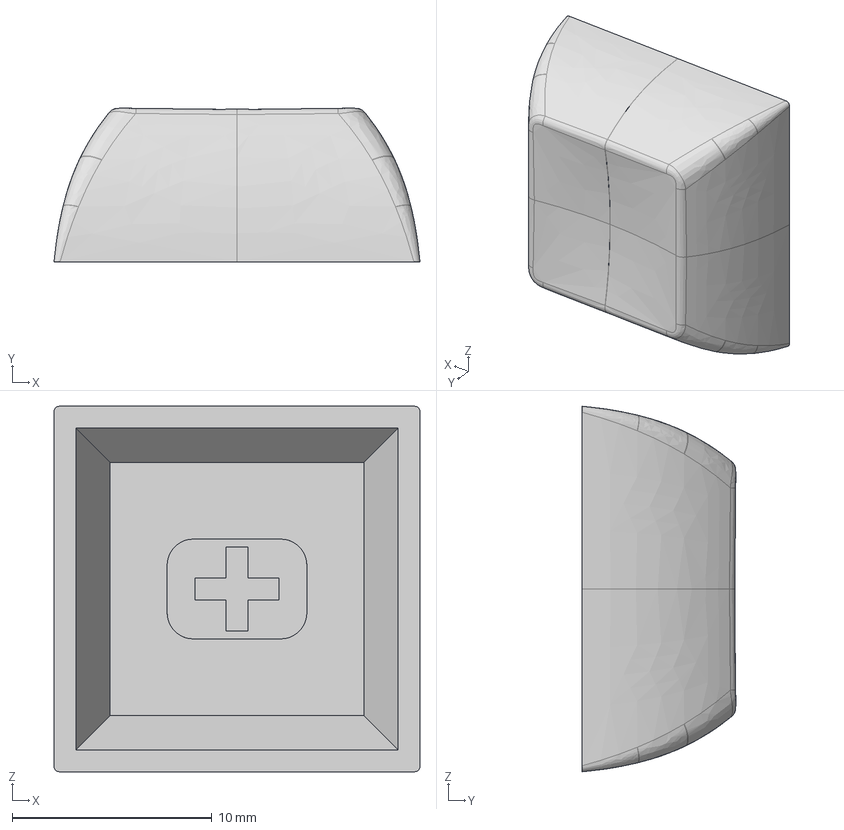
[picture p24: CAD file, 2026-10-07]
circuit/3D Models/DSA_Keycap_CherryMX.step
18.3 x 7.69 x 18.3 mm

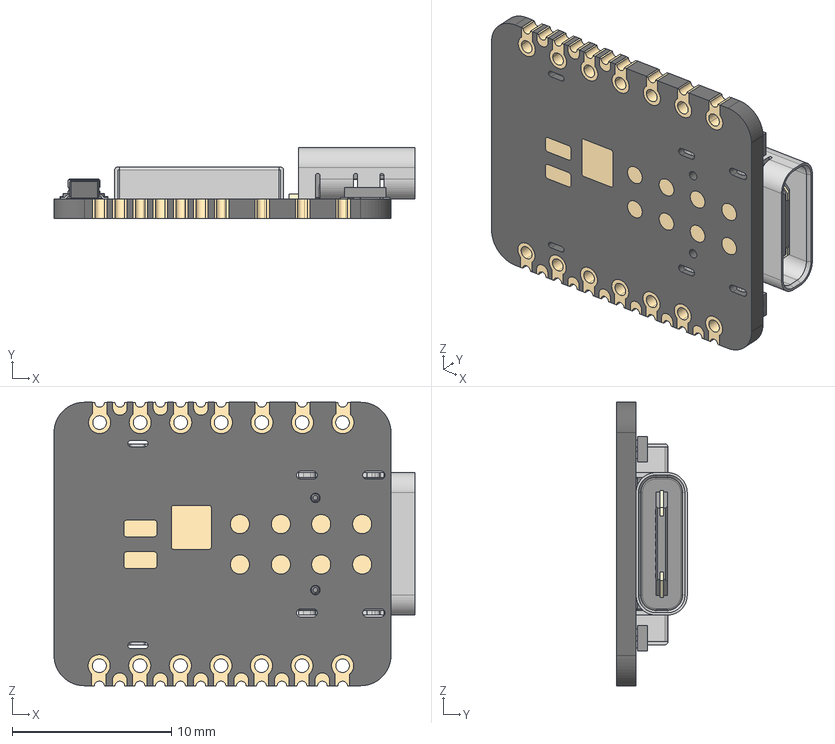
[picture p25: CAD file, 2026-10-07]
circuit/3D Models/XIAO ESP32S3 PLUS_.step
22.6 x 4.42 x 17.8 mm
DF40C-30DP-0.4V_51_ v1
BOSS-EXTRUDE14_8_
BOSS-EXTRUDE7_4_
BOSS-EXTRUDE7_3_
BOSS-EXTRUDE14_4_
BOSS-EXTRUDE14_2_
BOSS-EXTRUDE14_11_
BOSS-EXTRUDE7_7_
BOSS-EXTRUDE14_9_
BOSS-EXTRUDE14_3_
BOSS-EXTRUDE14_7_
MIRROR2
BOSS-EXTRUDE14_5_
BOSS-EXTRUDE14_12_
BOSS-EXTRUDE7_8_
BOSS-EXTRUDE7_1_
BOSS-EXTRUDE14_10_
BOSS-EXTRUDE7_9_
BOSS-EXTRUDE14_6_
BOSS-EXTRUDE14_1_
BOSS-EXTRUDE7_6_
BOSS-EXTRUDE7_2_
CUT-EXTRUDE5
BOSS-EXTRUDE7_5_
Shield
Pins x 2
U.FL-R-SMT-1_10_ v1

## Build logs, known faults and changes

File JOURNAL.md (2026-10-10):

# StarbieZ – devlog

<!-- Generated by Half Life from project cmuv2wpkk0cyp01sm96t8f5om. Edits here are overwritten on the next sync. -->
<!-- Generated: 2026-10-08T09:18:43.021Z -->

> [!NOTE]
> This devlog is mirrored from [Half Life](https://halflife.hackclub.com). Editing it here will not change the platform's copy, and the next sync overwrites this file.

> A tiny motion-controlled digital pet, basically a desktop Tamagotchi. Totally not a Starboy.

| Week | Tier | Hours logged | Entries |
| --- | --- | --- | --- |
| Week 1 | Tier 2 | 11h | 1 |

## Contents

1. [2026-10-08 – I started the work for this journal entry about 2 days ago. I worked on copying the PCB from the tutorial and modifying it. (*I didn't submit this journal entry earlier due to me thinking I could subm](#2026-10-08-i-started-the-work-for-this-journal-entry-about-2)

## Design

### 2026-10-08 – I started the work for this journal entry about 2 days ago. I worked on copying the PCB from the tutorial and modifying it. (*I didn't submit this journal entry earlier due to me thinking I could subm

**11h**

I started the work for this journal entry about 2 days ago. I worked on copying the PCB from the tutorial and modifying it. (*I didn't submit this journal entry earlier due to me thinking I could submit an entry on the StarbieZ project page and not the home page.)
I spent the whole day, and I quite probably went past 4 hours (the actual making time from the tutorial) to include the things that would make it my own.
The screenshot below shows the base schematic and there will be progression along the way of this entry a lot further from the typical tutorial board!



I then laid out my PCB, creating the `Edge.Cuts` star from a reference image I found on Google first (by searching up "pixel star", thanks Icons8):

pixel-star

I traced it by the pixel to get it into the project, though the grid settings were stuffing me up a little and I think I spent 40 minutes trying to trace it sufficiently.



I then meticulously traced out the ground plane by dragging the corners where they needed to be... (I know I could've just drew a square across the whole PCB and clicked B, I realized that after the fact!!) Oh yeah, and I almost forgot, *Microsoft Family Safety* kept prompting me to sign in to Microsoft services and wouldn't go away, I just disabled the parental controls service permanently because I got so frustrated (sorry Dad.)



I took a bold move after the 4 hours and 5 minutes mark, deciding to change the MCU. (spoiler: And it quickly spiraled to an ESP32-S3 Plus because I had the idea to make it expandible by the person..)



That swap over from the ESP32-C3 didn't take very long because the great thing with Seeed Studio XIAOs is they make them all extremely similar in structure. :)

Anyway, the next stupid thing I did was I chose to include an LDR for sensing light levels. It can be guessed that I also messed this one up bad and it set me back trying to find the correct new part, if you did guess that you are correct.



I put it on the right wing of the star PCB due to the ease of access to HEAPS of analog pins on that side, and I just had to measure analog signals, there was no other way out. I also added a third switch button, not thinking about clearance clearly (I'm such a goofball... and yet again, I would come to realize this later.)





A lot of organization, and another output was added to the project. A buzzer (or a piezo) was heavily inspired by the Sprig's design when I made my Columns game for them (still waiting for approval on that one), and I feel this Tamagotchi would do really well with a bit of tunes while flicking through the menu. (It's also an improvement in the matter of accessibility!)



I made some space in the star by increasing the area and I put it at the bottom of the board, and I even included a mini 100 ohm resistor on the side.. (it's R4!) I didn't want to choose SMD for debugging purposes, but I found SMD components are considerably better after routing traces to the XIAO...



After figuring out how to import *some* 3D models into the footprints, I found a honeycomb SVG icon on Flaticon (wow, cool name) that I really liked and I put it at the two bottom corners of the star. (PLEASE [!!] ignore the silkscreen warnings in DRC, they don't matter in this project about fab and production for this reason..)



(I'm a time-blind perfectionist writing this journal entry, sorry it's so long)

Around this time was the point I realized the 3rd switch had no clearance around the 6-axis IMU, and this was right after the switch to the ESP32-S3 Plus... so I expanded the area of my PCB yet again by a *slight bit* to fit the switch further down the star into its leg. I decided to place the buzzer against the screen so the GPIO header would be allowed free space. This is the chonkiness coming through :P





After this, I shut off the computer for the day and kept pondering in anxiety about whether I chose the right LDR. Turns out, as I would find out on Wednesday morning, the LDR I had chosen was completely off the market. I could not find it anywhere because its datasheet was *that* old. Yikes...

I done a little more research, switched the LDR to a generic one on KiCAD and documented my choice: the GL5528. I chose this because I found the dark resistance was around what I expected had been with 10 megaohms. I also switched out the 10 kilohm fixed resistor with an 100 kilohm one, so that the voltage I'd read in software would be a little more stable.

I asked Claude Sonnet 4.6 to make a scattered star SVG for me (because who creates SVGs by hand in plain text? I'm no graphic designer...) and I chose to put it on every corner of the star! I tested it inside JLCPCB and it looks ***SO*** cool when the PCB is white and the silkscreen is black, it makes this look like a professionally made product...!



sm_white_top 3

I put more techy explanation stuff in my GitHub repository, but this is the more personal journal entry. I'm kind of proud of myself as this is my second PCB ever, though I'm going to have a little trouble with just $30 funding. If anyone could help make this project more possible, I'd really appreciate it. Thanks for reading me rambling on! :3

I'll be working on the software for the next few days, I have lots planned that I'll journal in the GitHub instead of here because Hack Club Half-Life counts Hackatime hours into the final result. I'm just being fair...

[https://github.com/JustAnEric/starbiez/blob/main/README.md#day-1](https://github.com/JustAnEric/starbiez/blob/main/README.md#day-1)

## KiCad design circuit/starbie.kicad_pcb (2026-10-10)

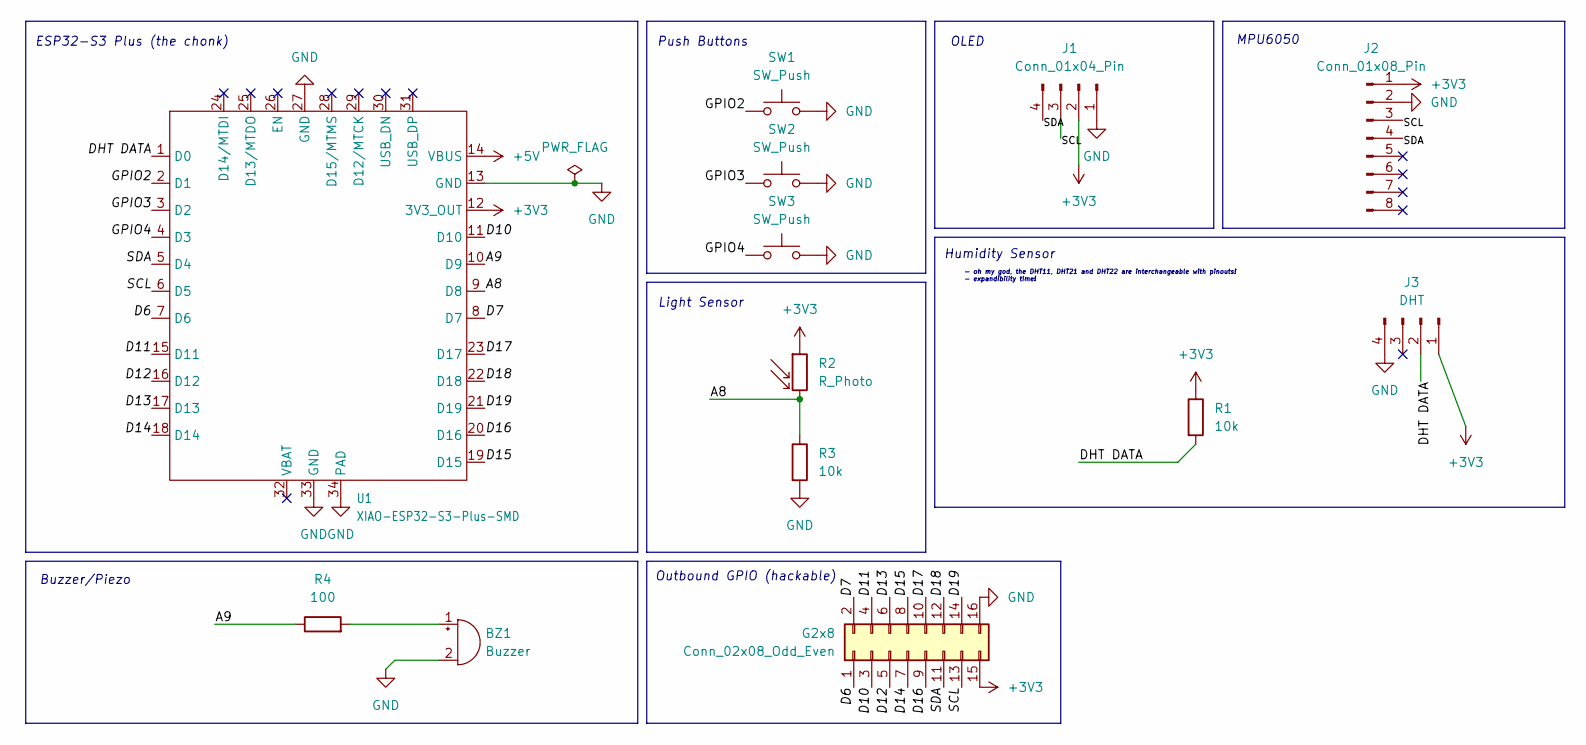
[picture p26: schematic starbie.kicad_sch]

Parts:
BZ1: Buzzer; Buzzer_12x9.5RM7.6
G2x8: Conn_02x08_Odd_Even; PinSocket_2x08_P2.54mm_Vertical
J1: Conn_01x04_Pin; Display_128x64_096_I2C
J2: Conn_01x08_Pin; MPU6050_Module
J3: DHT; PinSocket_1x04_P2.54mm_Vertical
R1, R3: 10k; R_Axial_DIN0204_L3.6mm_D1.6mm_P7.62mm_Horizontal
R2: R_Photo; R_LDR_4.9x4.2mm_P2.54mm_Vertical
R4: 100; R_Axial_DIN0204_L3.6mm_D1.6mm_P7.62mm_Horizontal
SW1, SW2, SW3: SW_Push; SW_Cherry_MX_1.00u_PCB
U1: XIAO-ESP32-S3-Plus-SMD

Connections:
+3V3: G2x8.15, J1.2, J2.1, J3.1, R1.1, R2.1, U1.12 (3V3_OUT); also elsewhere on the board
+5V: U1.14 (VBUS)
/A8: R2.2, R3.1, U1.9 (D8)
/A9: R4.1, U1.10 (D9)
/D6: G2x8.1, U1.7 (D6)
/D7: G2x8.2, U1.8 (D7)
/D10: G2x8.3, U1.11 (D10)
/D11: G2x8.4, U1.15 (D11)
/D12: G2x8.5, U1.16 (D12)
/D13: G2x8.6, U1.17 (D13)
/D14: G2x8.7, U1.18 (D14)
/D15: G2x8.8, U1.19 (D15)
/D16: G2x8.9, U1.20 (D16)
/D17: G2x8.10, U1.23 (D17)
/D18: G2x8.12, U1.22 (D18)
/D19: G2x8.14, U1.21 (D19)
/DHT DATA: J3.2, R1.2, U1.1 (D0); also elsewhere on the board
/GPIO2: SW1.1, U1.2 (D1)
/GPIO3: SW2.1, U1.3 (D2)
/GPIO4: SW3.1, U1.4 (D3)
/SCL: G2x8.13, J1.3, J2.3, U1.6 (D5)
/SDA: G2x8.11, J1.4, J2.4, U1.5 (D4)
GND: BZ1.2 (-), G2x8.16, J1.1, J2.2, J3.4, R3.2, SW1.2, SW2.2, SW3.2, U1.13 (GND), U1.27 (GND), U1.33 (GND), U1.34 (PAD); also elsewhere on the board
unnamed: BZ1.1 (+), R4.2

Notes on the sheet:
Outbound GPIO (hackable)
OLED
ESP32-S3 Plus (the chonk)
Buzzer/Piezo
Light Sensor
Push Buttons
Humidity Sensor
- oh my god, the DHT11, DHT21 and DHT22 are interchangeable with pinouts! - expandibility time!
MPU6050

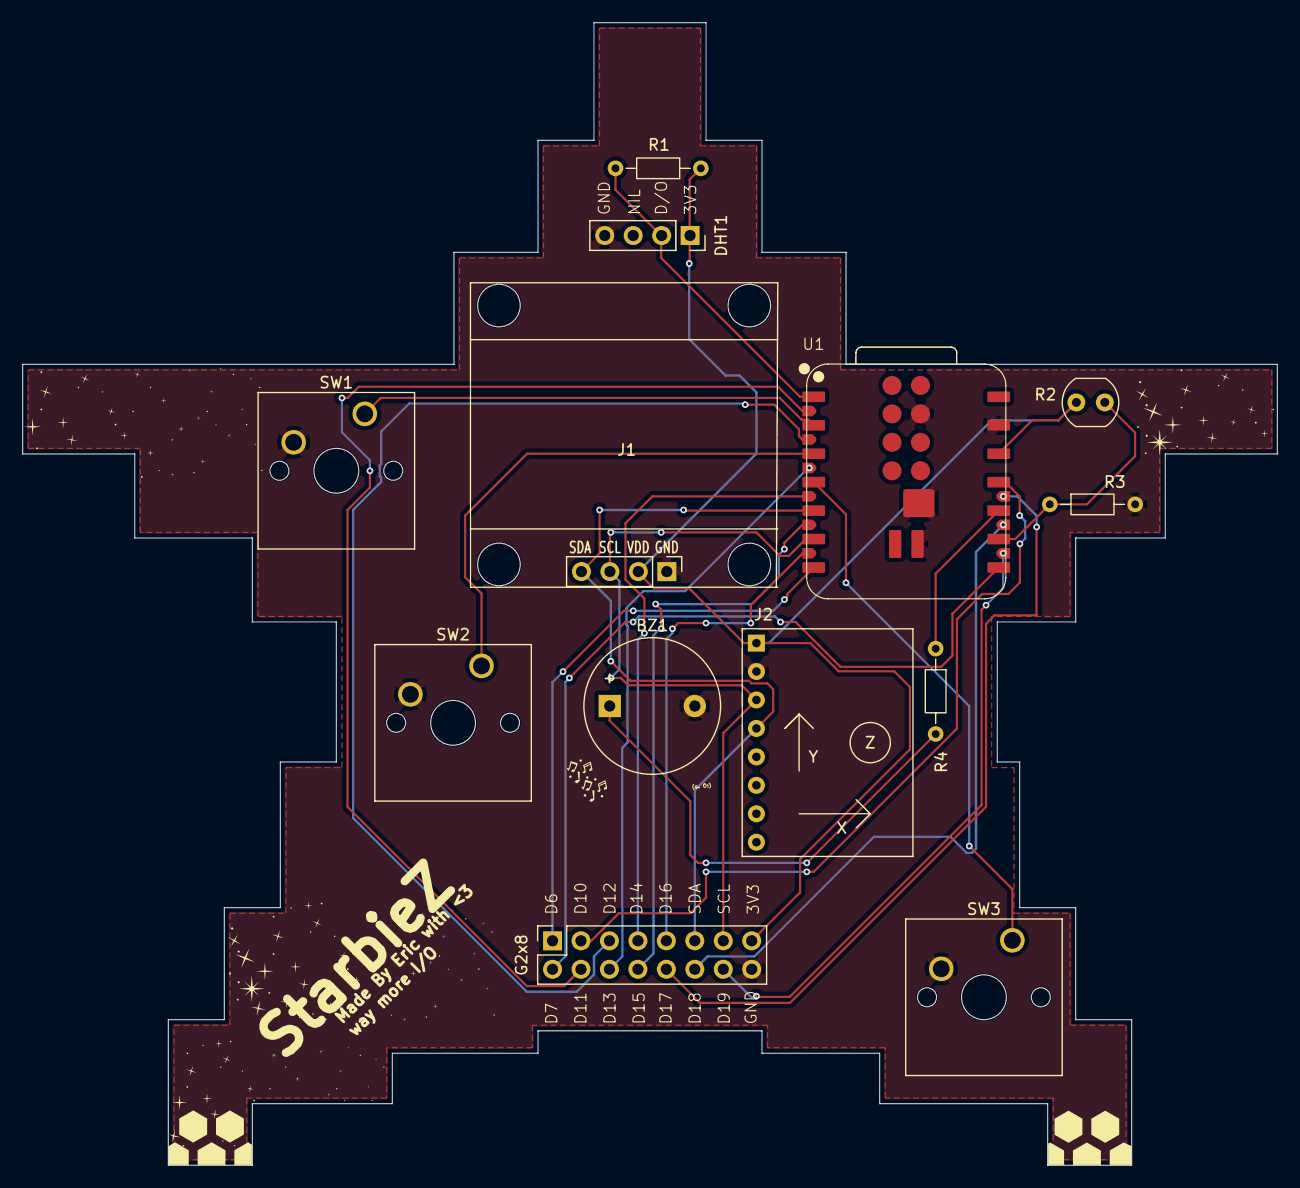
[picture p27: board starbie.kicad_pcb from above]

Board: 2 copper layers, 112.0 x 102.0 mm, 13 parts (0 on the bottom side), 23 nets.

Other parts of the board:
DHT1: DHT; PinSocket_1x04_P2.54mm_Vertical

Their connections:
+3V3: DHT1.1; also elsewhere on the board
/DHT DATA: DHT1.2; also elsewhere on the board
GND: DHT1.4; also elsewhere on the board

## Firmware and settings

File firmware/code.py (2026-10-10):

from utils.tama import globals, _types, sprites
from utils.starbie import is_starbie_board
from utils import logging, jerryscript_js, path, webserver
from typing import Union


import board
import digitalio
import time
import os
import math
import adafruit_ssd1306
import adafruit_framebuf
import adafruit_mpu6050
import adafruit_dht
import digitalio
import json

JSCRIPT_MODULES: list[dict] = []

class Main:
    def __init__(self):
        self.buttons: dict[_types.ButtonState, digitalio.DigitalInOut] = {}

        self.currentView : Union[str['PET_VIEW' | 'MENU_VIEW' | 'STATS_VIEW']] = ""
        self.petState : _types.PetState = _types.PetState(
            globals.STARTING_JOY, globals.STARTING_ENERGY,
            globals.STARTING_FULLNESS,
        )

        self.mpuFound = False
        self.dhtFound = False
        self.acceleration = _types.Axis3(x=0.0, y=0.0, z=globals.STANDARD_GRAVITY)
        self.temperatureC = -100000.0 # impossible in the real world
        self.humidity = -100000.0
        self.menuBall = [globals.MENU_CENTER_X, globals.MENU_CENTER_Y]
        self.menuCenterAcceleration : list[float, float] = [0.0, 0.0]
        self.selectedMenuItem = -1
        self.lastMpuReadAt = 0.0
        self.lastDhtReadAt = 0.0
        self.lastShakeAt = 0.0
        self.shakeAnimationEndsAt = 0.0
        self.petJumpStartedAt = 0.0
        self.nappingUntil = 0.0
        self.heartAnimationEndsAt = 0.0
        self.playRunStartedAt = 0.0
        self.nappingPetX = 0

        self.i2c = board.I2C()

        try:
            logging.msg_boot(f"using {globals.SCREEN_WIDTH}x{globals.SCREEN_HEIGHT} display on address {hex(globals.I2C.get("OLED_ADDRESS", 0x3C))} ({globals.I2C.get("OLED_ADDRESS", 0x3C)})")

            self.DISPLAY = adafruit_ssd1306.SSD1306_I2C(
                width=globals.SCREEN_WIDTH, 
                height=globals.SCREEN_HEIGHT, 
                i2c=self.i2c,
                addr=globals.I2C.get("OLED_ADDRESS", 0x3C)
            )
            self.DISPLAY.poweron()
            self.DISPLAY.fill(0)
        except:
            logging.msg_err("could not connect to display!!!")
            self.DISPLAY = None
            exit(3)

        try:
            logging.msg_boot(f"using MPU6050 IMU on address {hex(globals.I2C.get("MPU6050_ADDRESS", 0x68))} ({globals.I2C.get("MPU6050_ADDRESS", 0x68)})")

            self.MPU = adafruit_mpu6050.MPU6050(
                i2c_bus=self.i2c, 
                address=globals.I2C.get("MPU6050_ADDRESS", 0x68)
            )
            self.MPU.accelerometer_range = adafruit_mpu6050.Range.RANGE_8_G
            self.MPU.gyro_range = adafruit_mpu6050.GyroRange.RANGE_500_DPS
            self.MPU.filter_bandwidth = adafruit_mpu6050.Bandwidth.BAND_21_HZ
            self.mpuFound = True
        except:
            logging.msg_err("could not connect to MPU6050 IMU!!!")
            self.MPU = None
            self.mpuFound = False
            exit(3)


        if globals.USE_DHT:
            try:
                if globals.DHT_TYPE == "dht11":
                    logging.msg_boot(f"using DHT11 on pin {globals.DHT_PIN or 1}")

                    self.DHT = adafruit_dht.DHT11(
                        pin=globals.DHT_PIN or 1
                    )
                    self.dhtFound = True
                elif globals.DHT_TYPE == "dht21":
                    logging.msg_boot(f"using DHT21 on pin {globals.DHT_PIN or 1}")
                    
                    self.DHT = adafruit_dht.DHT21(
                        pin=globals.DHT_PIN or 1
                    )
                    self.dhtFound = True
                elif globals.DHT_TYPE == "dht22":
                    logging.msg_boot(f"using DHT22 on pin {globals.DHT_PIN or 1}")
                    
                    self.DHT = adafruit_dht.DHT22(
                        pin=globals.DHT_PIN or 1
                    )
                    self.dhtFound = True
                else:
                    logging.msg_warn(f"DHT was enabled but it seems you did not configure a DHT_TYPE value! On the common Starbiez, this value is just the 'dht22' if that helps. ({globals.DHT_PIN or 1})")
                    self.DHT = None
                    self.dhtFound = False
            except:
                logging.msg_warn(f"DHT was enabled but we could not find one connected to the pin selected! ({globals.DHT_PIN or 1})")
                self.DHT = None
                self.dhtFound = False
        else:
            logging.msg_boot(f"DHT was explicitly disabled, not loading")
            self.DHT = None
            self.dhtFound = False

    def load_pet(self):
        if path.exists(path="./user-data.json"):
            with open("./user-data.json", "r") as fp:
                pets_data = json.load(fp)
                fp.close()
            self.petState.joy = pets_data.get('starbie',{}).get('joy', globals.STARTING_JOY)
            self.petState.energy = pets_data.get('starbie',{}).get('energy', globals.STARTING_ENERGY)
            self.petState.fullness = pets_data.get('starbie',{}).get('fullness', globals.STARTING_FULLNESS)
        else:
            # file doesn't exist
            payload = {
                'starbie': {
                    'joy': globals.STARTING_JOY,
                    'energy': globals.STARTING_ENERGY,
                    'fullness': globals.STARTING_FULLNESS
                }
            }
            with open("./user-data.json", "w") as fp:
                json.dump(payload, fp, indent=4)
            self.petState.joy = payload.get('starbie').get('joy')
            self.petState.energy = payload.get('starbie').get('energy')
            self.petState.fullness = pets_data.get('starbie').get('fullness')

    def save_pet(self):
        payload = {
            'starbie': {
                'joy': self.petState.joy,
                'energy': self.petState.energy,
                'fullness': self.petState.fullness
            }
        }
        with open("./user-data.json", "w") as fp:
            json.dump(payload, fp, indent=4)

    def change_pet(self, joyChange: int, energyChange: int, fullnessChange: int):
        self.petState.joy = self.constrain(self.petState.joy + joyChange, 0, 100)
        self.petState.energy = self.constrain(self.petState.energy + energyChange, 0, 100)
        self.petState.fullness = self.constrain(self.petState.fullness + fullnessChange, 0, 100)
        self.save_pet()

    def add_button(self, pin: int):
        button = digitalio.DigitalInOut(pin=pin)
        button.direction = digitalio.Direction.INPUT
        button.pull = button.pull.UP
        buttonState = _types.ButtonState(
            pin=pin, 
            stableState=button.value, 
            lastRawState=button.value, 
            lastChangedAt=time.time(),
            realButton=button
        )
        self.buttons[buttonState] = button

    def get_button(self, pin: int) -> _types.ButtonState | None:
        for button in self.buttons:
            if button.pin == pin:
                return button
        return None

    def was_button_pressed(self, button: _types.ButtonState):
        rawState = button.realButton.value
        now = time.time()
        if rawState != button.lastRawState:
            button.lastRawState = rawState
            button.lastChangedAt = now
        if (rawState != button.stableState and now - button.lastChangedAt >= self._ms_to_s(globals.BUTTON_DEBOUNCE_MS)):
            button.stableState = rawState
            return button.stableState == False
        return False

    def _ms_to_s(self, v: int):
        return v/1000

    def update_mpu(self):
        now = time.time()
        if (not self.mpuFound or not self.MPU) or (now - self.lastMpuReadAt < self._ms_to_s(globals.MPU_READ_INTERVAL_MS)):
            return
        self.lastMpuReadAt = now
        accel = self.MPU.acceleration
        self.acceleration = _types.Axis3(x=accel[0], y=accel[1], z=accel[2])

    def update_dht(self):
        now = time.time()
        if (not self.dhtFound or not self.DHT) or (now - self.lastDhtReadAt < self._ms_to_s(globals.DHT_READ_INTERVAL_MS)):
            return
        self.lastDhtReadAt = now
        try:
            self.humidity = self.DHT.humidity
            self.temperatureC = self.DHT.temperature
        except RuntimeError:
            logging.msg_warn("mild error while updating DHT stats")
            pass

    def pet_walking_x(self, now: float):
        """
        `now` should be in seconds
        """
        farthestX = globals.SCREEN_WIDTH - globals.PET_SPRITE_WIDTH
        roundTrip = farthestX * 2
        step = (now / self._ms_to_s(globals.PET_WALK_PIXEL_MS)) % roundTrip
        return step if step <= farthestX else roundTrip - step

    def play_run_duration(self) -> float:
        """
        in seconds
        """
        return self._ms_to_s(globals.PLAY_LAP_MS) * globals.PLAY_LAP_COUNT

    def is_napping(self) -> bool:
        return self.nappingUntil != 0 and time.time() < self.nappingUntil

    def is_playing(self) -> bool:
        return self.playRunStartedAt != 0 and time.time() - self.playRunStartedAt < self.play_run_duration()

    def play_run_x(self, now: float):
        """
        `now` should be in seconds
        """
        farthestX = globals.SCREEN_WIDTH - globals.PET_SPRITE_WIDTH
        lapAge = (now - self.playRunStartedAt) % self._ms_to_s(globals.PLAY_LAP_MS)
        progress = lapAge / self._ms_to_s(globals.PLAY_LAP_MS)
        return int(progress * 2.0 * farthestX) if progress < 0.5 else int((1.0 - progress) * 2.0 * farthestX)

    def update_pet_timers(self):
        if self.nappingUntil != 0 and not self.is_napping():
            self.nappingUntil = 0
        if self.playRunStartedAt != 0 and not self.is_playing():
            self.playRunStartedAt = 0

    def constrain(self, val: float, minv: float, maxv: float):
        return max(minv, min(val, maxv))

    def update_menu_ball(self):
        xTilt = self.acceleration.x - self.menuCenterAcceleration[0]
        yTilt = self.acceleration.y - self.menuCenterAcceleration[1]
        if globals.SWAP_MPU_AXES:
            oldXTilt = xTilt
            xTilt = yTilt
            yTilt = oldXTilt
        xTilt = self.constrain(xTilt * globals.MENU_X_DIRECTION, -globals.MENU_TILT_LIMIT, globals.MENU_TILT_LIMIT)
        yTilt = self.constrain(yTilt * globals.MENU_Y_DIRECTION, -globals.MENU_TILT_LIMIT, globals.MENU_TILT_LIMIT)
        targetX = globals.MENU_CENTER_X + (xTilt / globals.MENU_TILT_LIMIT) * globals.MENU_BALL_X_RANGE
        targetY = globals.MENU_CENTER_Y + (yTilt / globals.MENU_TILT_LIMIT) * globals.MENU_BALL_Y_RANGE

        menuBallX += (targetX - menuBallX) * 0.20
        menuBallY += (targetY - menuBallY) * 0.20

        fbfXTilt = abs(xTilt)
        fbfYTilt = abs(yTilt)

        if fbfXTilt < globals.MENU_CENTER_DEADZONE and fbfYTilt < globals.MENU_CENTER_DEADZONE:
            self.selectedMenuItem = -1
        elif fbfXTilt > fbfYTilt:
            self.selectedMenuItem = 1 if xTilt > 0.0 else 3 # r or l
        else:
            self.selectedMenuItem = 2 if yTilt > 0.0 else 0 # b or t

    def check_for_shake(self):
        if (not self.mpuFound or not self.MPU) or self.currentView != 'PET_VIEW':
            return

        mag = self.sqrtf(self.acceleration.x * self.acceleration.x +
                         self.acceleration.y * self.acceleration.y +
                         self.acceleration.z * self.acceleration.z)
        now = time.time()
        if abs(mag - globals.STANDARD_GRAVITY) >= globals.SHAKE_THRESHOLD and now - self.lastShakeAt >= self._ms_to_s(globals.SHAKE_COOLDOWN_MS):
            self.lastShakeAt = now
            self.nappingUntil = 0
            self.shakeAnimationEndsAt = now + 350
            self.change_pet(globals.SHAKE_JOY_CHANGE, globals.SHAKE_ENERGY_CHANGE, globals.SHAKE_FULLNESS_CHANGE)
            self.save_pet()

    def open_menu(self):
        self.currentView = "MENU_VIEW"
        self.selectedMenuItem = -1
        self.menuBall[0] = globals.MENU_CENTER_X
        self.menuBall[1] = globals.MENU_CENTER_Y
        self.menuCenterAcceleration[0] = self.acceleration.x
        self.menuCenterAcceleration[1] = self.acceleration.y

    def choose_menu_item(self):
        if self.selectedMenuItem == -1:
            return

        item = globals.MENU_ITEMS[self.selectedMenuItem]
        self.change_pet(item.joyChange, item.energyChange, item.fullnessChange)
        self.save_pet()
        now = time.time()
        self.nappingUntil = 0
        self.heartAnimationEndsAt = 0
        self.playRunStartedAt = 0

        if item.reaction == _types.PetReaction.NAP_REACTION:
            self.petJumpStartedAt = 0
            self.nappingPetX = self.pet_walking_x(now=now)
            self.nappingUntil = now + self._ms_to_s(globals.NAP_DURATION_MS)
        elif item.reaction == _types.PetReaction.RUN_REACTION:
            self.petJumpStartedAt = 0
            self.playRunStartedAt = now
            self.heartAnimationEndsAt = now + self.play_run_duration()
        else:
            self.petJumpStartedAt = now
            if item.reaction == _types.PetReaction.HEART_REACTION:
                self.heartAnimationEndsAt = now + self._ms_to_s(globals.HEARTS_DURATION_MS)
        
        self.currentView = "PET_VIEW"

    def handle_buttons(self):
        button1 = self.get_button(pin=globals.BUTTON.get("BUTTON_ONE_PIN", 2))
        button2 = self.get_button(pin=globals.BUTTON.get("BUTTON_TWO_PIN", 3))

        if self.was_button_pressed(button=button1):
            if self.currentView == "MENU_VIEW":
                self.choose_menu_item()
            else:
                self.open_menu()

        if self.was_button_pressed(button=button2):
            self.currentView = "PET_VIEW" if self.currentView == "STATS_VIEW" else "STATS_VIEW"

    def draw_heart(self, x: int, y: int):
        SSD1306_WHITE = 1
        self.DISPLAY.fill_rect(x - 2, y, 2, 2, SSD1306_WHITE)
        self.DISPLAY.fill_rect(x + 1, y, 2, 2, SSD1306_WHITE)
        self.DISPLAY.fill_rect(x - 3, y + 2, 7, 2, SSD1306_WHITE)
        self.DISPLAY.fill_rect(x - 2, y + 4, 5, 1, SSD1306_WHITE)
        self.DISPLAY.fill_rect(x - 1, y + 5, 3, 1, SSD1306_WHITE)
        self.DISPLAY.pixel(x, y + 6, SSD1306_WHITE)

    def draw_hearts(self, now: float, petX: int, petY: int):
        """
        `now` in seconds
        """
        if now >= self.heartAnimationEndsAt:
            return

        progress = 1.0 - (self.heartAnimationEndsAt - now) / self._ms_to_s(globals.HEARTS_DURATION_MS)
        rise = progress * 18.0
        self.draw_heart(petX + 10, petY - 3 - rise)
        self.draw_heart(petX + 22, petY - 9 - rise / 2)

    def draw_sleep_zs(self, now: float, petX: int, petY: int):
        """
        `now` in seconds
        """
        rise = (now / 300) % 15
        self.DISPLAY.text("z", petX + 23, petY - 2 - rise)
        self.DISPLAY.text("z", petX + 28, petY - 8 - rise / 2)

    def draw_pet(self):
        SSD1306_WHITE = 1
        self.DISPLAY.fill(0)
        now = time.time()
        petX = self.nappingPetX if self.is_napping() else self.pet_walking_x(now=now)
        if self.is_playing():
            petX = self.play_run_x(now=now)
        petY = globals.SCREEN_HEIGHT - globals.PET_SPRITE_HEIGHT

        if now < self.shakeAnimationEndsAt:
            petX += (math.sin(now / 18.0) * 3.0)

        if not self.is_napping() and self.petJumpStartedAt != 0:
            animationAge = now - self.petJumpStartedAt

            if animationAge < self._ms_to_s(globals.PET_PRE_JUMP_MS):
                petX += (math.sin(now / 16.0) * 3.0)
            elif animationAge < self._ms_to_s(globals.PET_PRE_JUMP_MS) + self._ms_to_s(globals.PET_JUMP_MS):
                jumpProgress = animationAge - self._ms_to_s(globals.PET_PRE_JUMP_MS) / self._ms_to_s(globals.PET_JUMP_MS)
                petY -= (math.sin(jumpProgress * math.pi) * globals.PET_JUMP_HEIGHT)
            else:
                self.petJumpStartedAt = 0

        petX = self.constrain(petX, 0, globals.SCREEN_WIDTH - globals.PET_SPRITE_WIDTH)
        asset_buf = adafruit_framebuf.FrameBuffer(
            sprites.PET_SPRITE_001,
            globals.PET_SPRITE_WIDTH, globals.PET_SPRITE_HEIGHT,
            adafruit_framebuf.MHMSBFormat
        )

        self.DISPLAY.blit(asset_buf, petX, petY, SSD1306_WHITE)

        if self.is_napping():
            self.draw_sleep_zs(now, petX, petY)
        self.draw_hearts(now, petX, petY)

    def draw_round_rect(self, x: int, y: int, w: int, h: int, r, color, fill=False):
        if r <= 0:
            if fill:
                self.DISPLAY.fill_rect(x, y, w, h, color)
            else:
                self.DISPLAY.rect(x, y, w, h, color)
            return

        # restrict maximum radius calculation to avoid distort
        r = min(r, w // 2, h // 2)

        if fill:
            # draw center block and horizontal extensions
            self.DISPLAY.fill_rect(x + r, y, w - 2 * r, h, color)
            self.DISPLAY.fill_rect(x, y + r, r, h - 2 * r, color)
            self.DISPLAY.fill_rect(x + w - r, y + r, r, h - 2 * r, color)
        else:
            # draw direct boundary edges
            self.DISPLAY.hline(x + r, y, w - 2 * r, color)          # t boundary
            self.DISPLAY.hline(x + r, y + h - 1, w - 2 * r, color)  # b boundary
            self.DISPLAY.vline(x, y + r, h - 2 * r, color)          # l boundary
            self.DISPLAY.vline(x + w - 1, y + r, h - 2 * r, color)  # r boundary

        cx, cy = r, 0
        d = 1 - r

        while cx >= cy:
            # tl corner
            self.DISPLAY.pixel(x + r - cy, y + r - cx, color)
            self.DISPLAY.pixel(x + r - cx, y + r - cy, color)
            if fill:
                self.DISPLAY.hline(x + r - cx, y + r - cy, cx, color)
                self.DISPLAY.hline(x + r - cy, y + r - cx, cy, color)

            # tr corner
            self.DISPLAY.pixel(x + w - r - 1 + cy, y + r - cx, color)
            self.DISPLAY.pixel(x + w - r - 1 + cx, y + r - cy, color)
            if fill:
                self.DISPLAY.hline(x + w - r - 1, y + r - cy, cx, color)
                self.DISPLAY.hline(x + w - r - 1, y + r - cx, cy, color)

            # bl corner
            self.DISPLAY.pixel(x + r - cy, y + h - r - 1 + cx, color)
            self.DISPLAY.pixel(x + r - cx, y + h - r - 1 + cy, color)
            if fill:
                self.DISPLAY.hline(x + r - cx, y + h - r - 1 + cy, cx, color)
                self.DISPLAY.hline(x + r - cy, y + h - r - 1 + cx, cy, color)

            # br corner
            self.DISPLAY.pixel(x + w - r - 1 + cy, y + h - r - 1 + cx, color)
            self.DISPLAY.pixel(x + w - r - 1 + cx, y + h - r - 1 + cy, color)
            if fill:
                self.DISPLAY.hline(x + w - r - 1, y + h - r - 1 + cy, cx, color)
                self.DISPLAY.hline(x + w - r - 1, y + h - r - 1 + cx, cy, color)

            cy += 1
            if d < 0:
                d += 2 * cy + 1
            else:
                cx -= 1
                d += 2 * (cy - cx) + 1

    def draw_circle(self, x0, y0, r, color, fill=False):
        # big math
        x = r
        y = 0
        err = 0

        while x >= y:
            if fill:
                # draw horizontal lines between symmetric points to fill the space
                self.DISPLAY.hline(x0 - x, y0 + y, 2 * x + 1, color)
                self.DISPLAY.hline(x0 - x, y0 - y, 2 * x + 1, color)
                self.DISPLAY.hline(x0 - y, y0 + x, 2 * y + 1, color)
                self.DISPLAY.hline(x0 - y, y0 - x, 2 * y + 1, color)
            else:
                # plot the 8 octant outline points
                self.DISPLAY.pixel(x0 + x, y0 + y, color)
                self.DISPLAY.pixel(x0 + y, y0 + x, color)
                self.DISPLAY.pixel(x0 - y, y0 + x, color)
                self.DISPLAY.pixel(x0 - x, y0 + y, color)
                self.DISPLAY.pixel(x0 - x, y0 - y, color)
                self.DISPLAY.pixel(x0 - y, y0 - x, color)
                self.DISPLAY.pixel(x0 + y, y0 - x, color)
                self.DISPLAY.pixel(x0 + x, y0 - y, color)

            y += 1
            if err <= 0:
                err += 2 * y + 1
            else:
                x -= 1
                err += 2 * (y - x) + 1

    def draw_menu_item(self, item: int):
        boxWidth = 33
        boxHeight = 12
        boxX = globals.MENU_ITEM_X[item] - boxWidth / 2
        boxY = globals.MENU_ITEM_Y[item] - boxHeight / 2
        isSelected = item == self.selectedMenuItem

        textColor = 0
        if isSelected:
            self.draw_round_rect(boxX, boxY, boxWidth, boxHeight, 3, 1)
        else:
            self.draw_round_rect(boxX, boxY, boxWidth, boxHeight, 3, 0)
            textColor = 1

        labelLength = len(globals.MENU_ITEMS[item].label)
        self.DISPLAY.text(globals.MENU_ITEMS[item].label, globals.MENU_ITEM_X[item] - labelLength * 3, globals.MENU_ITEM_Y[item] - 3, textColor)

    def draw_menu(self):
        self.DISPLAY.fill(0)
        self.DISPLAY.line(0, 0, globals.SCREEN_WIDTH - 1, globals.SCREEN_HEIGHT - 1, 1)
        self.DISPLAY.line(0, globals.SCREEN_HEIGHT - 1, globals.SCREEN_WIDTH - 1, 0, 1)

        for item in range(globals.MENU_ITEM_COUNT):
            self.draw_menu_item(item)

        self.draw_circle(globals.MENU_CENTER_X, globals.MENU_CENTER_Y, 11, 1)
        self.draw_circle(int(self.menuBall[0]), int(self.menuBall[1]), 4, 1, True)

    def draw_stat_bar(self, y: int, label: str, value: int):
        self.DISPLAY.text(label, 4, y, 1)
        self.DISPLAY.rect(48, y, 57, 8, 1)
        width = int((value * 55) / 100)
        self.DISPLAY.fill_rect(49, y + 1, width, 6, 1)
        self.DISPLAY.text(value, 109, y, 1)
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

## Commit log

2026-10-07 Journal writeup finished for PCB
    [0.96'' OLED Display.step, Cherry MX.STEP, DSA_Keycap_CherryMX.step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]
2026-10-07 Add necessary PCB prod files
    [bom-autogenerated.csv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]
2026-10-10 Upload new files for Starbiez
    [bom.csv, designators.csv, positions.csv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]
2026-10-10 PCB fixes (added expandibility for DHT!)
    [positions.csv, starbie.kicad_pcb]
